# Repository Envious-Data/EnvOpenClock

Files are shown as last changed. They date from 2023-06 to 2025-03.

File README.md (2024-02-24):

# Env-OpenClock
 A fancy lil clock using 8x LTP-305s and a Raspberry Pi Pico.

## Information
This clock features a DS3231 but it doesnt have its own onboard battery management meaning its meant to have constant power but there is nothing stopping anyone from soldering something like a pico lipo shim to the back of the PCB. The RTC is mainly for convenience.

There are 4 buttons and a switch, The switch is meant for Summer time adjustment and the 4 buttons are for setting the time or alarm.

## Implemented Features
- Time Setting
- Date Mode

## Planned software features
(Some ideas, may not get implemented)
- Animated text to show time has been set?
- Animated Transition to menus?
- A menu system
- Alarm system
- Text Marquee modes

## Planned Hardware features
In the current version of the board there is a a DS3231 w/ CR1220 battery, Raspberry pi pico, 4x tactile buttons, 4x IS31FL37s, a small piezo speaker and amp and obviously the 8x LTP305 sockets.

We'd like to change this to have easier to press buttons, a larger battery holder, the speaker may not get re-implemented, we'll see when we decide to move toward finalizing the design and preparing for order. Keep in mind that TIL305s have been discontinued for a long time and LTP305s are now discontinued and hard to get so we'll substitute our own "DIY305" which is a dip14 sized PCB with standard headers and 0402 leds but we have made a 0201 version but may not use it due to cost.

## Hardware
I designed the board in KiCad, you can use various plugins to generate production files for your chosen PCB FAB
Some aspects may change but I generally intend to keep the formfactor the same and all the components on one side for cheaper manufacturing.

since the board uses 8x LTP305s you can also display the date instead of the time, the RTC does store the date as well as the time, currently as of writing this the firmware only displays the current time stored on the DS3231 RTC, but the main planned features are day/date/time setting and then goals can expand. Its possible to add text marquee too.

## PCBWAY
PCBWAY (http://pcbway.com)

[PCBWAY](http://pcbway.com) Kindly sponsored a batch of PCBs of which you can see a video of the board working below

https://github.com/Envious-Data/Env-OpenClock/assets/5001879/fdac6cdb-803a-443c-b91d-f5f40f54c28f

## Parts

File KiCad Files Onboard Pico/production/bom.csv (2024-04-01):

Designator | Footprint | Quantity | Value | LCSC Part #
BT1 | BatteryHolder_Keystone_3034_1x20mm | 1 | Keystone 3034
BZ1 | Buzzer_TDK_PS1240P02BT_D12.2mm_H6.5mm | 1 | Buzzer 12.2Mm
C1, C3, C33, C5, C7, C9 | 0402 | 6 | 0402 0.1uF
C10, C2, C4, C6, C8 | 0402 | 5 | 0402 1uF
C11, C12, C13, C14 | 0402 | 4 | 0402 10uF
C16, C17 | 0402 | 2 | 22pf 0402
C18, C21, C22, C24, C26, C27, C28, C29, C30, C31 | 0402 | 10 | 100nf 0402
C19, C20, CBP1 | 0402 | 3 | 10uf 0402
C23 | 0402 | 1 | 1uf 0402
C25 | 0402 | 1 | 2.2uF 0402
D1 | D_SOD-123 | 1 | 1N4002W
F1 | 0805 | 1 | 0805L050WR
FB1 | 0402 | 1 | FerriteBead 0402
FLASH1 | SON-8-1EP_3x2mm_P0.5mm_EP1.4x1.6mm | 1 | W25Q16JVUXIQ
H1, H2, H3, H4 | MountingHole_2.2mm_M2 | 4 | M2
IC1, IC2, IC3, IC4 | QFN-24-1EP_4x4mm_P0.5mm_EP2.6x2.6mm_ThermalVias | 4 | IS31FL3730-QFLS2-TR
J1 | PinHeader_1x03_P1.00mm_Vertical | 1 | 1mm 1x3
J3 | SW_Push_SPST_NO_Alps_SKRK | 1 | Button
JP1 | SolderJumper-2_P1.3mm_Bridged_RoundedPad1.0x1.5mm | 1 | bridge
JP2, JP3 | SolderJumper-2_P1.3mm_Open_RoundedPad1.0x1.5mm | 2 | bridge
M1, M2, M3, M4, M5, M6, M7, M8 | DIP-14_W7.62mm_Socket | 8 | Dip-14 Socket
Q1 | SOT-23 | 1 | 2SC1815
R1, R10, R11, R12, R13, R2, R28, R5, R6, R7, R8, R9 | 0402 | 12 | 0402 10K
R15, R16 | 0402 | 2 | 5.1K 0402
R18, R23 | 0402 | 2 | 1K 0402
R21 | 0402 | 1 | 10K 0402
R22 | 0402 | 1 | 100K 0402
R24, R25 | 0402 | 2 | 27r 0402 resistor
R3, R4 | 0805 | 2 | 0805 1K
RSW1 | SW_Push_SPST_NO_Alps_SKRK | 1 | TSA343G00-250J2
SW1, SW2, SW3, SW4, SW5 | SW_Cherry_MX_1.00u_PCB | 5 | MX Keyboard Switch
TP1, TP2, TP3 | TestPoint_Pad_D1.0mm | 3 | TestPoint
U1 | DFN-6-1EP_3x3mm_P1mm_EP1.5x2.4mm | 1 | Si7021-A20
U2 | SOT-23-5 | 1 | TLV75733PDBVR
U3 | SOIC-16W_7.5x10.3mm_P1.27mm | 1 | DS3231M
U4 | RP2040-QFN-56 | 1 | RP2040 | C2040
USB1 | USB_C_Receptacle_HRO_TYPE-C-31-M-12 | 1 | TYPE-C-31-M-12 | C165948
Y1 | Crystal_SMD_3225-4Pin_3.2x2.5mm | 1 | 3225_4P 12MHz

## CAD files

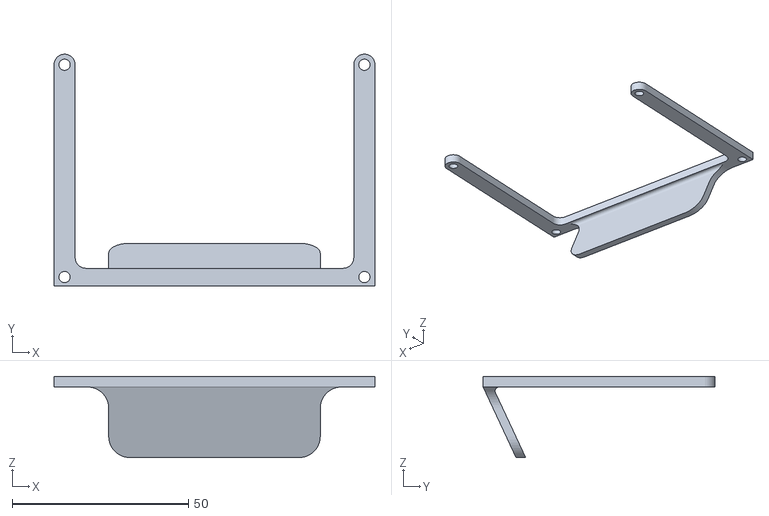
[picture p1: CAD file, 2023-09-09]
3d files/Simple Stand.stl
91.0 x 65.7 x 23.0

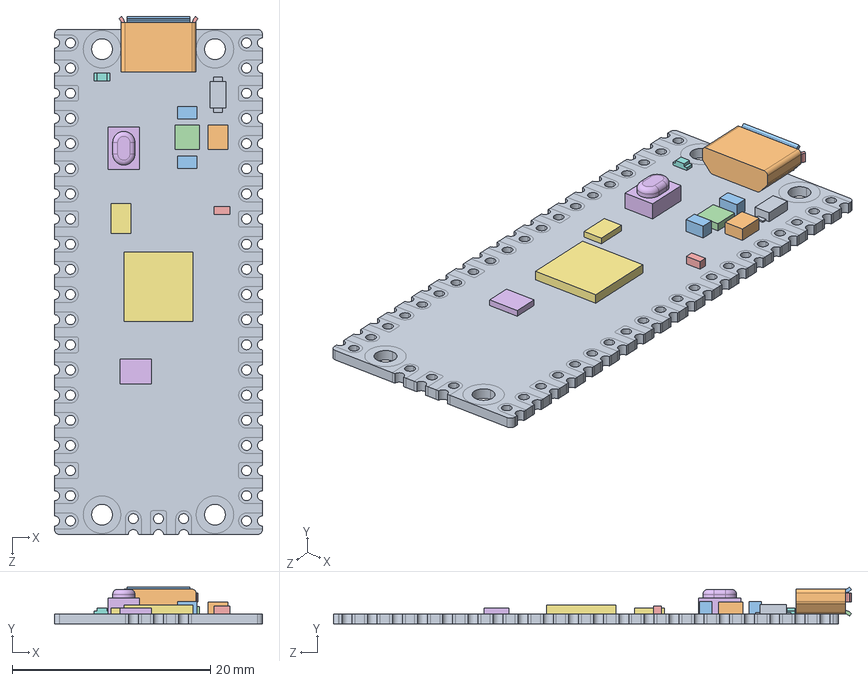
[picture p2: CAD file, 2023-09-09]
KiCad Files Onboard Pico/Resources/Pico-R3.step
21.0 x 3.73 x 52.3 mm
PICO_REF_BOARD.STEP
PICO_REF_USB.STEP
PICO_REF_SWITCH.STEP
PICO_REF_MICROCONTROLLER.STEP
PICO_REF_LED.STEP
PICO_REF_ONSEMI.STEP
PICO_BOURNS.STEP
PICO_MURATA.STEP x 2
PICO_RICHTEK.STEP
PICO_DIODES.STEP
PICO_AEL.STEP
PICO_WINBOND.STEP

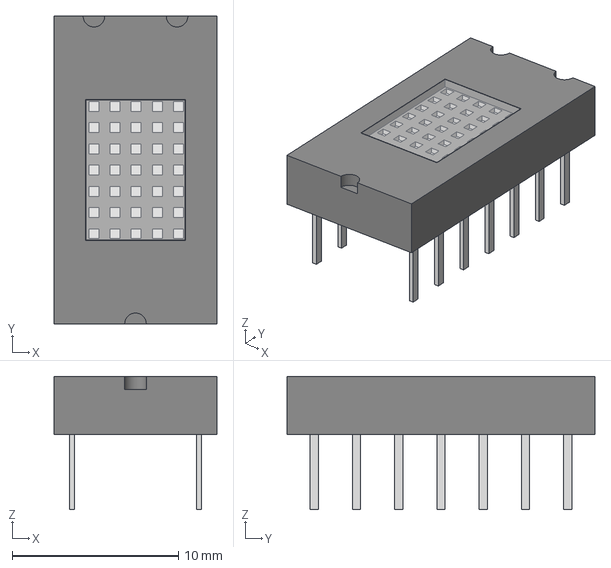
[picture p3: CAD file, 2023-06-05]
KiCad Files Onboard Pico/Resources/LTP-305G.stp
9.80 x 18.5 x 8.00 mm

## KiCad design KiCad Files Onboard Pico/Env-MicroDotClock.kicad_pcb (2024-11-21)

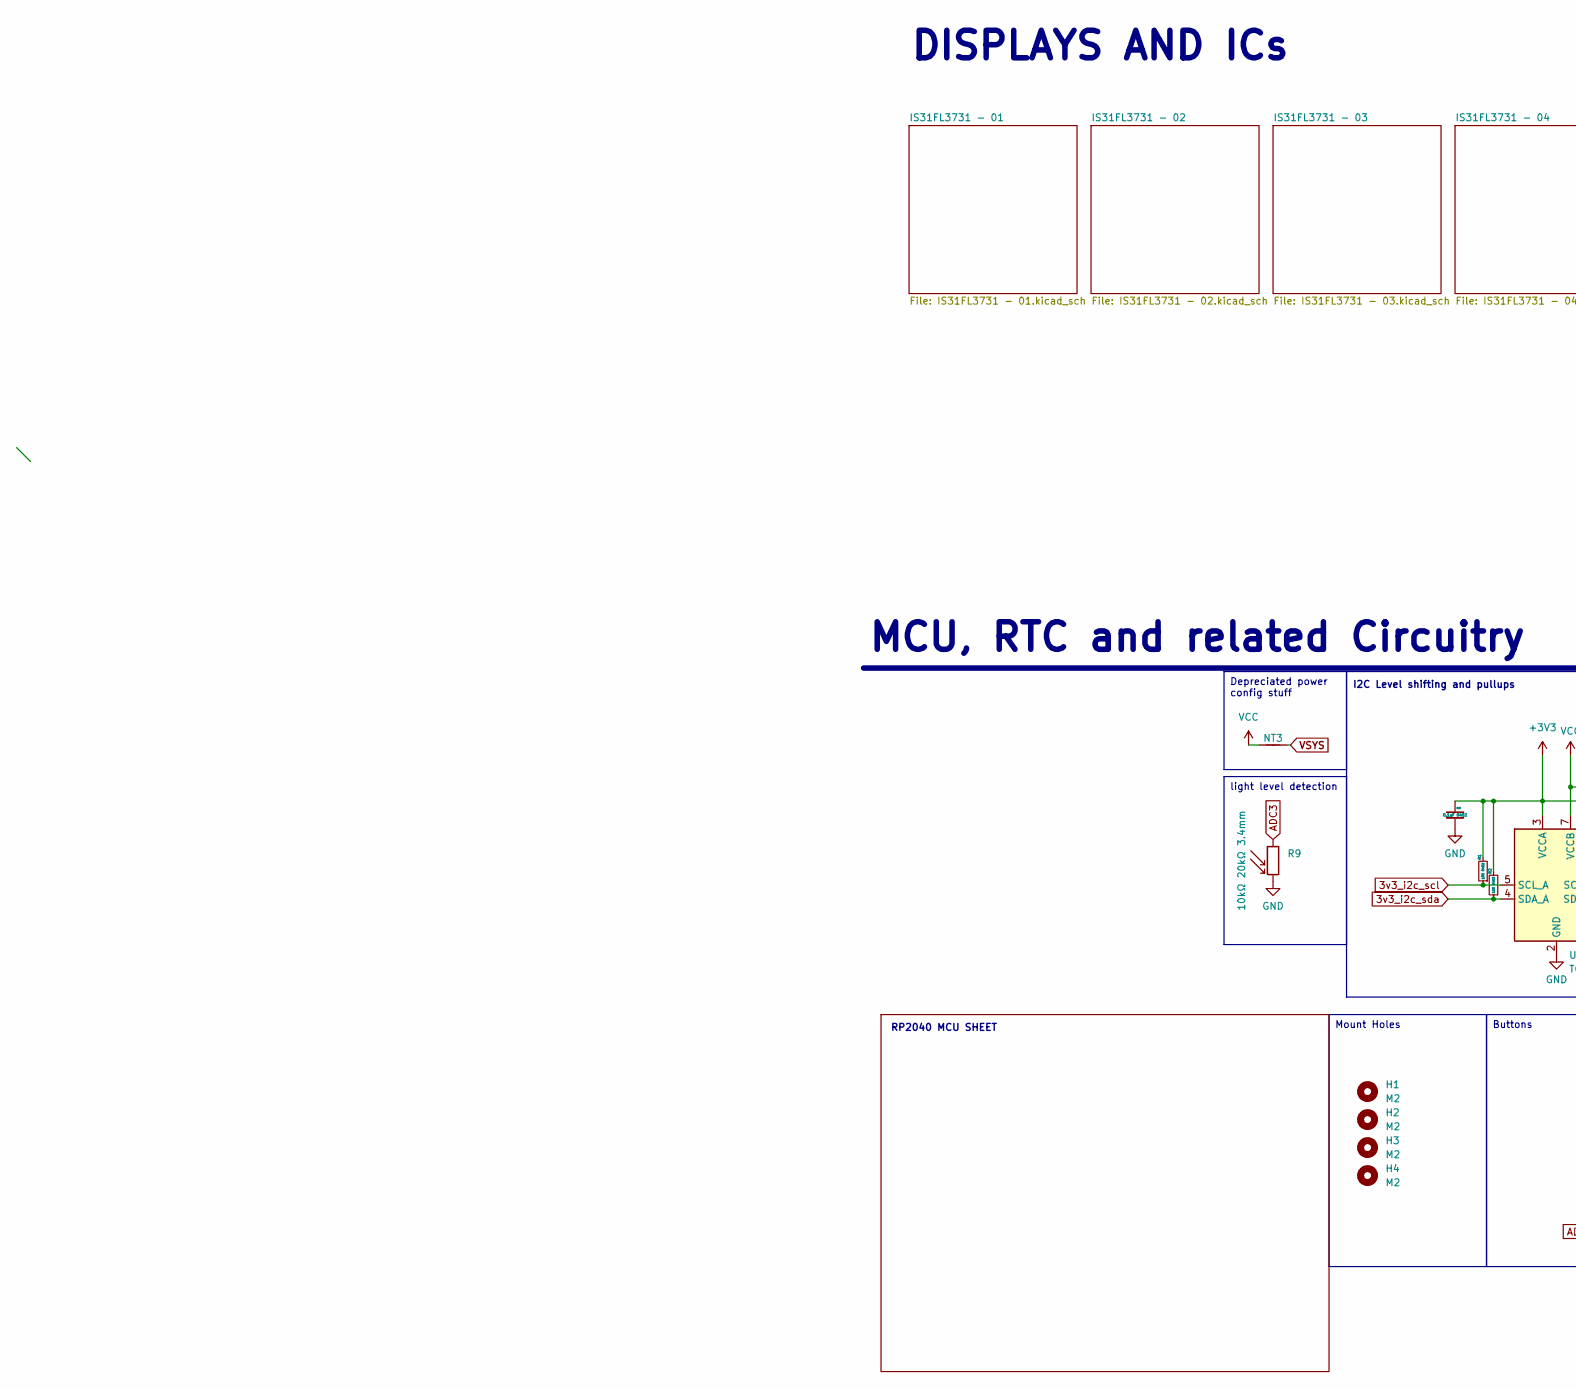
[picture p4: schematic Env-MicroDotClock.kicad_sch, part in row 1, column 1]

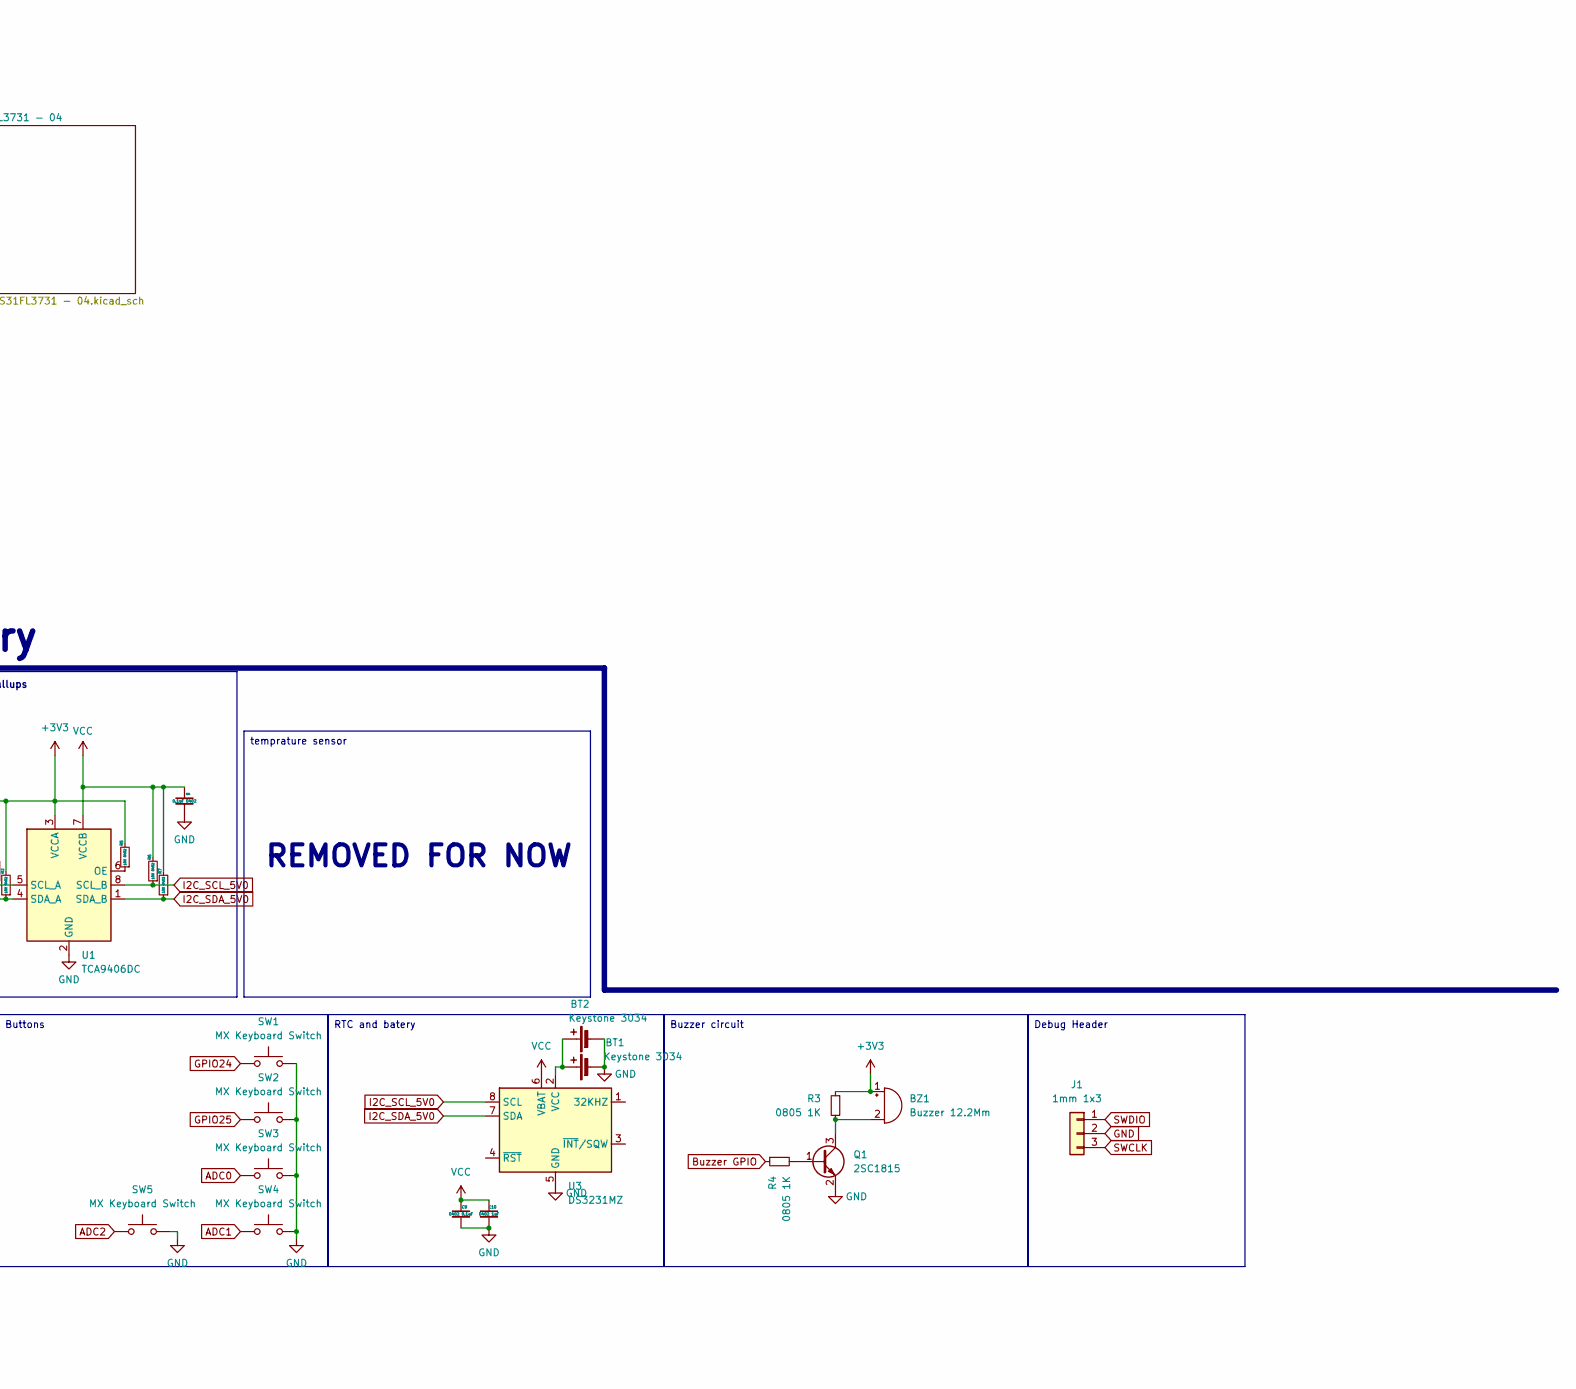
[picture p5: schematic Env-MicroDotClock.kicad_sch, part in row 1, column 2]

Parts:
BT1, BT2: Keystone 3034; BatteryHolder_Keystone_3034_1x20mm
BZ1: Buzzer 12.2Mm; Buzzer_TDK_PS1240P02BT_D12.2mm_H6.5mm
C9: 0402 0.1uF; C_0402_1005Metric
C10: 0402 1uF; C_0402_1005Metric
C33, C34: 0.1uF 0402; C_0402_1005Metric
H1, H2, H3, H4: M2; MountingHole_2.2mm_M2
J1: 1mm 1x3; PinHeader_1x03_P1.00mm_Vertical
NT3: NetTie_2; NetTie-2_THT_Pad0.3mm
Q1: 2SC1815; SOT-23
R1, R2, R5, R6, R7: 10K 0402; R_0402_1005Metric
R3, R4: 0805 1K; R_0805_2012Metric
R9: 10kΩ 20kΩ 3.4mm; R_LDR_5.1x4.3mm_P3.4mm_Vertical
SW1, SW2, SW3, SW4, SW5: MX Keyboard Switch; SW_Cherry_MX_1.00u_PCB
U1: TCA9406DC; VSSOP-8_2.3x2mm_P0.5mm
U3: DS3231MZ; SOIC-8_3.9x4.9mm_P1.27mm

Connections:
3v3_i2c_scl: R1.1, U1.5 (SCL_A); also elsewhere on the board
3v3_i2c_sda: R2.1, U1.4 (SDA_A); also elsewhere on the board
+3V3: BZ1.1 (-), C33.1, R1.2, R2.2, R3.1, R5.2, U1.3 (VCCA); also elsewhere on the board
ADC0: SW3.1; also elsewhere on the board
ADC1: SW4.1; also elsewhere on the board
ADC2: SW5.1; also elsewhere on the board
ADC3: R9.1; also elsewhere on the board
Buzzer GPIO: R4.1; also elsewhere on the board
GND: BT1.2 (-), BT2.2 (-), C9.2, C10.2, C33.2, C34.2, J1.2, Q1.2 (E), R9.2, SW1.2, SW2.2, SW3.2, SW4.2, SW5.2, U1.2 (GND), U3.5 (GND); also elsewhere on the board
GPIO24: SW1.1; also elsewhere on the board
GPIO25: SW2.1; also elsewhere on the board
I2C_SCL_5V0: R6.1, U1.8 (SCL_B), U3.8 (SCL); also elsewhere on the board
I2C_SDA_5V0: R7.1, U1.1 (SDA_B), U3.7 (SDA); also elsewhere on the board
unnamed: BT1.1 (+), BT2.1 (+), U3.2 (VCC)
unnamed: BZ1.2 (+), Q1.3 (C), R3.2
unnamed: Q1.1 (B), R4.2
unnamed: R5.1, U1.6 (OE)
SWCLK: J1.3; also elsewhere on the board
SWDIO: J1.1; also elsewhere on the board
VCC: C9.1, C10.1, C34.1, NT3.1, R6.2, R7.2, U1.7 (VCCB), U3.6 (VBAT); also elsewhere on the board
VSYS: NT3.2; also elsewhere on the board

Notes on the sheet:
light level detection
RTC and batery
Mount Holes
Depreciated power config stuff
Buzzer circuit
Debug Header
Buttons
temprature sensor
DISPLAYS AND ICs
MCU, RTC and related Circuitry
RP2040 MCU SHEET
I2C Level shifting and pullups
REMOVED FOR NOW

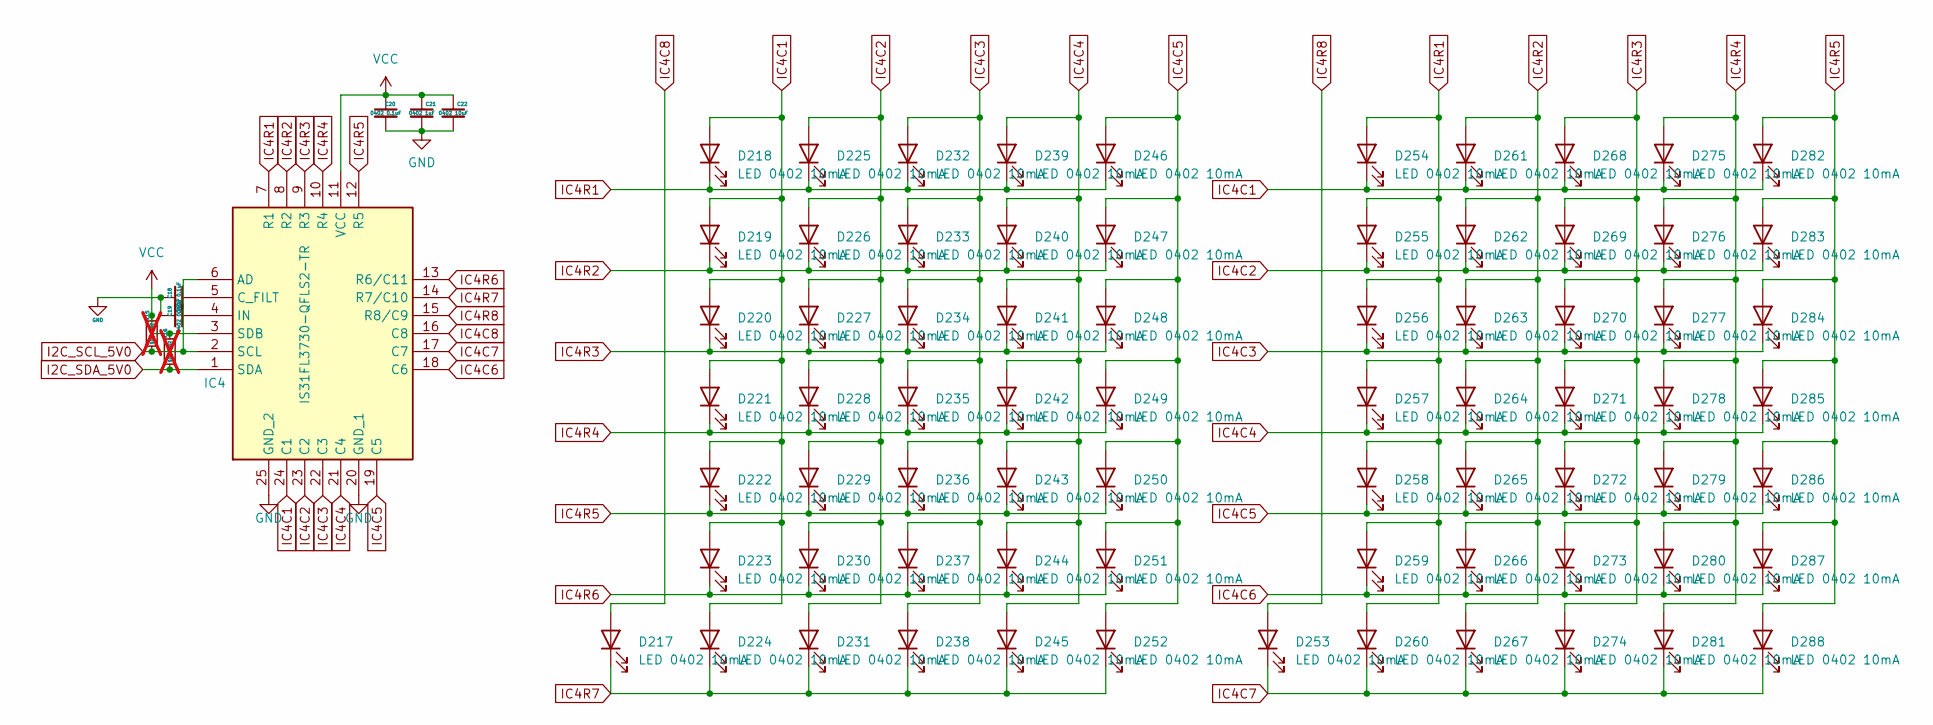
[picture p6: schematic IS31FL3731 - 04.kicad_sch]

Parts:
C18, C20: 0402 0.1uF; C_0402_1005Metric
C19: 0402 0.22uF; C_0402_1005Metric
C21: 0402 1uF; C_0402_1005Metric
C22: 0402 10uF; C_0402_1005Metric
D217, D218, D219, D220, D221, D222, D223, D224, D225, D226, D227, D228, D229, D230, D231, D232, D233, D234, D235, D236, D237, D238, D239, D240, D241, D242, D243, D244, D245, D246, D247, D248, D249, D250, D251, D252, D253, D254, D255, D256, D257, D258, D259, D260, D261, D262, D263, D264, D265, D266, D267, D268, D269, D270, D271, D272, D273, D274, D275, D276, D277, D278, D279, D280, D281, D282, D283, D284, D285, D286, D287, D288: LED 0402 10mA; LED_0402_1005Metric
IC4: IS31FL3730-QFLS2-TR; QFN-24-1EP_4x4mm_P0.5mm_EP2.6x2.6mm_ThermalVias; Mouser Part Number 870-IS31FL3730QFLS2R
R15, R16: 10K 0402; R_0402_1005Metric; not fitted

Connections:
GND: C18.1, C19.1, C20.2, C21.2, C22.2, IC4.20 (GND_1), IC4.25 (GND_2); also elsewhere on the board
I2C_SCL_5V0: IC4.2 (SCL), IC4.6 (AD), R15.1; also elsewhere on the board
I2C_SDA_5V0: IC4.1 (SDA), R16.1; also elsewhere on the board
IC4C1: D218.2 (A), D219.2 (A), D220.2 (A), D221.2 (A), D222.2 (A), D223.2 (A), D224.2 (A), D254.1 (K), D261.1 (K), D268.1 (K), D275.1 (K), D282.1 (K), IC4.24 (C1)
IC4C2: D225.2 (A), D226.2 (A), D227.2 (A), D228.2 (A), D229.2 (A), D230.2 (A), D231.2 (A), D255.1 (K), D262.1 (K), D269.1 (K), D276.1 (K), D283.1 (K), IC4.23 (C2)
IC4C3: D232.2 (A), D233.2 (A), D234.2 (A), D235.2 (A), D236.2 (A), D237.2 (A), D238.2 (A), D256.1 (K), D263.1 (K), D270.1 (K), D277.1 (K), D284.1 (K), IC4.22 (C3)
IC4C4: D239.2 (A), D240.2 (A), D241.2 (A), D242.2 (A), D243.2 (A), D244.2 (A), D245.2 (A), D257.1 (K), D264.1 (K), D271.1 (K), D278.1 (K), D285.1 (K), IC4.21 (C4)
IC4C5: D246.2 (A), D247.2 (A), D248.2 (A), D249.2 (A), D250.2 (A), D251.2 (A), D252.2 (A), D258.1 (K), D265.1 (K), D272.1 (K), D279.1 (K), D286.1 (K), IC4.19 (C5)
IC4C6: D259.1 (K), D266.1 (K), D273.1 (K), D280.1 (K), D287.1 (K), IC4.18 (C6)
IC4C7: D253.1 (K), D260.1 (K), D267.1 (K), D274.1 (K), D281.1 (K), D288.1 (K), IC4.17 (C7)
IC4C8: D217.2 (A), IC4.16 (C8)
IC4R1: D218.1 (K), D225.1 (K), D232.1 (K), D239.1 (K), D246.1 (K), D254.2 (A), D255.2 (A), D256.2 (A), D257.2 (A), D258.2 (A), D259.2 (A), D260.2 (A), IC4.7 (R1)
IC4R2: D219.1 (K), D226.1 (K), D233.1 (K), D240.1 (K), D247.1 (K), D261.2 (A), D262.2 (A), D263.2 (A), D264.2 (A), D265.2 (A), D266.2 (A), D267.2 (A), IC4.8 (R2)
IC4R3: D220.1 (K), D227.1 (K), D234.1 (K), D241.1 (K), D248.1 (K), D268.2 (A), D269.2 (A), D270.2 (A), D271.2 (A), D272.2 (A), D273.2 (A), D274.2 (A), IC4.9 (R3)
IC4R4: D221.1 (K), D228.1 (K), D235.1 (K), D242.1 (K), D249.1 (K), D275.2 (A), D276.2 (A), D277.2 (A), D278.2 (A), D279.2 (A), D280.2 (A), D281.2 (A), IC4.10 (R4)
IC4R5: D222.1 (K), D229.1 (K), D236.1 (K), D243.1 (K), D250.1 (K), D282.2 (A), D283.2 (A), D284.2 (A), D285.2 (A), D286.2 (A), D287.2 (A), D288.2 (A), IC4.12 (R5)
IC4R6: D223.1 (K), D230.1 (K), D237.1 (K), D244.1 (K), D251.1 (K), IC4.13 (R6/C11)
IC4R7: D217.1 (K), D224.1 (K), D231.1 (K), D238.1 (K), D245.1 (K), D252.1 (K), IC4.14 (R7/C10)
IC4R8: D253.2 (A), IC4.15 (R8/C9)
unnamed: C18.2, IC4.5 (C_FILT)
unnamed: C19.2, IC4.4 (IN)
VCC: C20.1, C21.1, C22.1, IC4.3 (SDB), IC4.11 (VCC), R15.2, R16.2; also elsewhere on the board

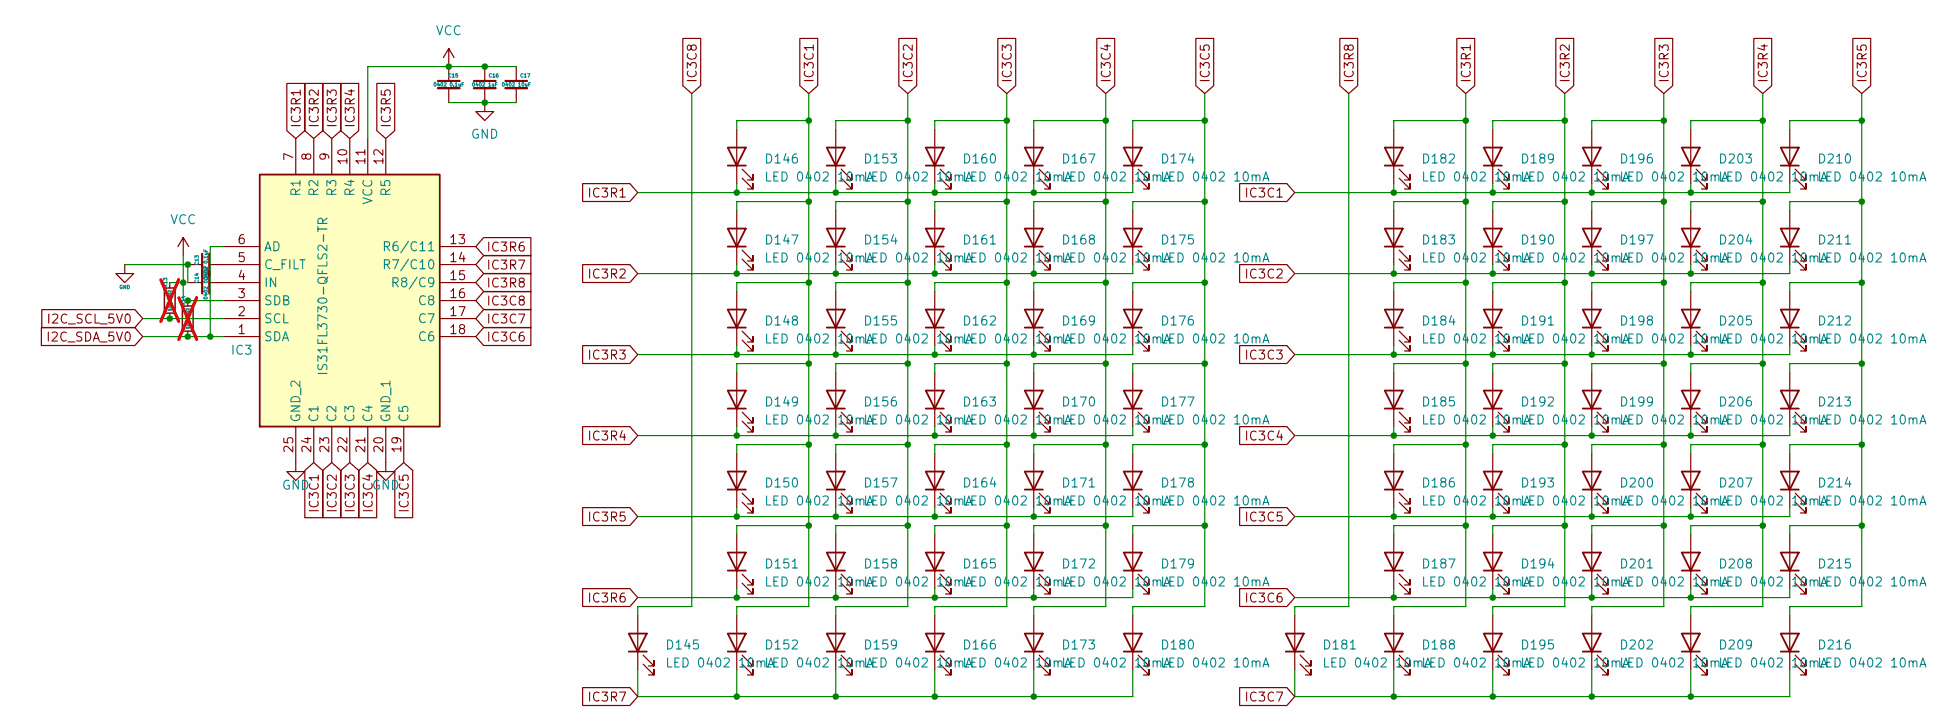
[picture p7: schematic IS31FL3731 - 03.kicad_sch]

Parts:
C13, C15: 0402 0.1uF; C_0402_1005Metric
C14: 0402 0.22uF; C_0402_1005Metric
C16: 0402 1uF; C_0402_1005Metric
C17: 0402 10uF; C_0402_1005Metric
D145, D146, D147, D148, D149, D150, D151, D152, D153, D154, D155, D156, D157, D158, D159, D160, D161, D162, D163, D164, D165, D166, D167, D168, D169, D170, D171, D172, D173, D174, D175, D176, D177, D178, D179, D180, D181, D182, D183, D184, D185, D186, D187, D188, D189, D190, D191, D192, D193, D194, D195, D196, D197, D198, D199, D200, D201, D202, D203, D204, D205, D206, D207, D208, D209, D210, D211, D212, D213, D214, D215, D216: LED 0402 10mA; LED_0402_1005Metric
IC3: IS31FL3730-QFLS2-TR; QFN-24-1EP_4x4mm_P0.5mm_EP2.6x2.6mm_ThermalVias; Mouser Part Number 870-IS31FL3730QFLS2R
R13, R14: 10K 0402; R_0402_1005Metric; not fitted

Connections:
GND: C13.1, C14.1, C15.2, C16.2, C17.2, IC3.20 (GND_1), IC3.25 (GND_2); also elsewhere on the board
I2C_SCL_5V0: IC3.2 (SCL), R13.1; also elsewhere on the board
I2C_SDA_5V0: IC3.1 (SDA), IC3.6 (AD), R14.1; also elsewhere on the board
IC3C1: D146.2 (A), D147.2 (A), D148.2 (A), D149.2 (A), D150.2 (A), D151.2 (A), D152.2 (A), D182.1 (K), D189.1 (K), D196.1 (K), D203.1 (K), D210.1 (K), IC3.24 (C1)
IC3C2: D153.2 (A), D154.2 (A), D155.2 (A), D156.2 (A), D157.2 (A), D158.2 (A), D159.2 (A), D183.1 (K), D190.1 (K), D197.1 (K), D204.1 (K), D211.1 (K), IC3.23 (C2)
IC3C3: D160.2 (A), D161.2 (A), D162.2 (A), D163.2 (A), D164.2 (A), D165.2 (A), D166.2 (A), D184.1 (K), D191.1 (K), D198.1 (K), D205.1 (K), D212.1 (K), IC3.22 (C3)
IC3C4: D167.2 (A), D168.2 (A), D169.2 (A), D170.2 (A), D171.2 (A), D172.2 (A), D173.2 (A), D185.1 (K), D192.1 (K), D199.1 (K), D206.1 (K), D213.1 (K), IC3.21 (C4)
IC3C5: D174.2 (A), D175.2 (A), D176.2 (A), D177.2 (A), D178.2 (A), D179.2 (A), D180.2 (A), D186.1 (K), D193.1 (K), D200.1 (K), D207.1 (K), D214.1 (K), IC3.19 (C5)
IC3C6: D187.1 (K), D194.1 (K), D201.1 (K), D208.1 (K), D215.1 (K), IC3.18 (C6)
IC3C7: D181.1 (K), D188.1 (K), D195.1 (K), D202.1 (K), D209.1 (K), D216.1 (K), IC3.17 (C7)
IC3C8: D145.2 (A), IC3.16 (C8)
IC3R1: D146.1 (K), D153.1 (K), D160.1 (K), D167.1 (K), D174.1 (K), D182.2 (A), D183.2 (A), D184.2 (A), D185.2 (A), D186.2 (A), D187.2 (A), D188.2 (A), IC3.7 (R1)
IC3R2: D147.1 (K), D154.1 (K), D161.1 (K), D168.1 (K), D175.1 (K), D189.2 (A), D190.2 (A), D191.2 (A), D192.2 (A), D193.2 (A), D194.2 (A), D195.2 (A), IC3.8 (R2)
IC3R3: D148.1 (K), D155.1 (K), D162.1 (K), D169.1 (K), D176.1 (K), D196.2 (A), D197.2 (A), D198.2 (A), D199.2 (A), D200.2 (A), D201.2 (A), D202.2 (A), IC3.9 (R3)
IC3R4: D149.1 (K), D156.1 (K), D163.1 (K), D170.1 (K), D177.1 (K), D203.2 (A), D204.2 (A), D205.2 (A), D206.2 (A), D207.2 (A), D208.2 (A), D209.2 (A), IC3.10 (R4)
IC3R5: D150.1 (K), D157.1 (K), D164.1 (K), D171.1 (K), D178.1 (K), D210.2 (A), D211.2 (A), D212.2 (A), D213.2 (A), D214.2 (A), D215.2 (A), D216.2 (A), IC3.12 (R5)
IC3R6: D151.1 (K), D158.1 (K), D165.1 (K), D172.1 (K), D179.1 (K), IC3.13 (R6/C11)
IC3R7: D145.1 (K), D152.1 (K), D159.1 (K), D166.1 (K), D173.1 (K), D180.1 (K), IC3.14 (R7/C10)
IC3R8: D181.2 (A), IC3.15 (R8/C9)
unnamed: C13.2, IC3.5 (C_FILT)
unnamed: C14.2, IC3.4 (IN)
VCC: C15.1, C16.1, C17.1, IC3.3 (SDB), IC3.11 (VCC), R13.2, R14.2; also elsewhere on the board

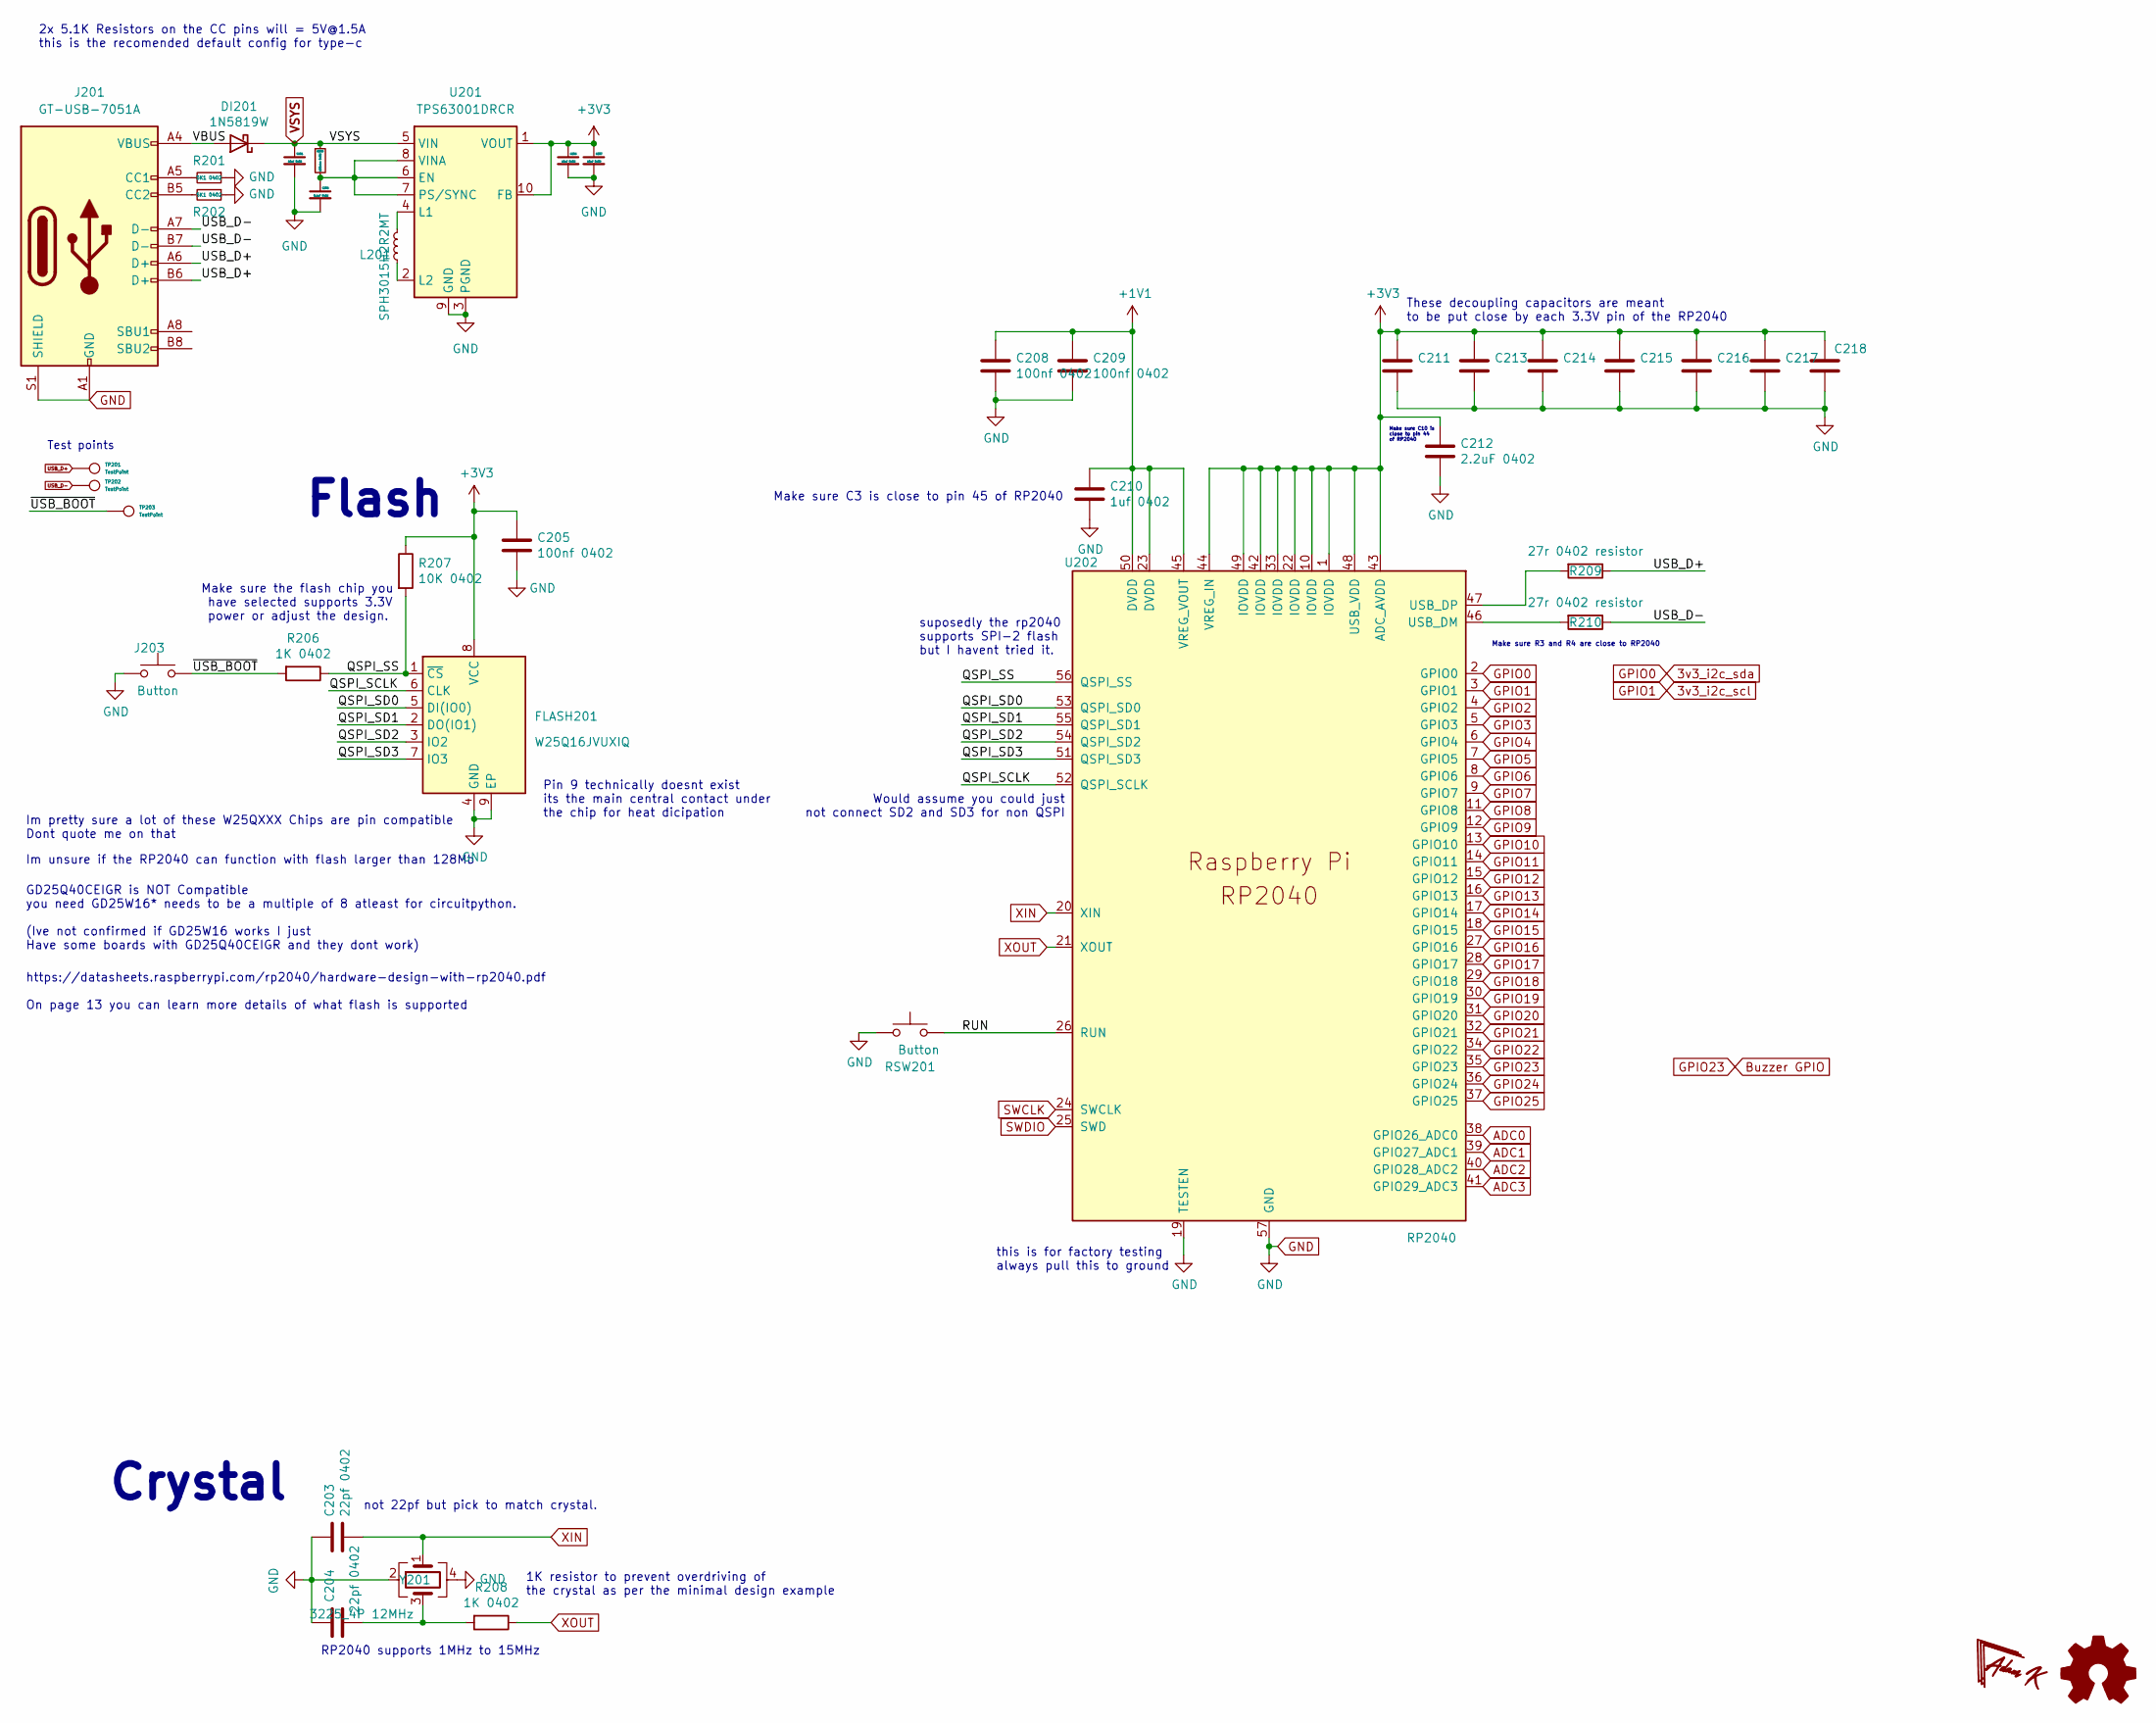
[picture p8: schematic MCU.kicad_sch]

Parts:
C201, C206, C207: 10uF 0402; C_0402_1005Metric
C202: 0.1uF 0402; C_0402_1005Metric
C203, C204: 22pf 0402; C_0402_1005Metric
C205, C208, C209, C211, C213, C214, C215, C216, C217, C218: 100nf 0402; C_0402_1005Metric
C210: 1uf 0402; C_0402_1005Metric
C212: 2.2uF 0402; C_0402_1005Metric
DI201: 1N5819W; D_SOD-123
FLASH201: W25Q16JVUXIQ; SON-8-1EP_3x2mm_P0.5mm_EP1.4x1.6mm
J201: GT-USB-7051A; USB_C_Receptacle_G-Switch_GT-USB-7051x
J203: Button; SW_SPST_B3U-1000P-B
L201: SPH3015H2R2MT; L_Sunlord_SWPA3015S
R201, R202: 5K1 0402; R_0402_1005Metric
R205: 100ohm 0402; R_0402_1005Metric
R206, R208: 1K 0402; R_0402_1005Metric
R207: 10K 0402; R_0402_1005Metric
R209, R210: 27r 0402 resistor; R_0402_1005Metric
RSW201: Button; SW_SPST_B3U-1000P-B
TP201, TP202, TP203: TestPoint; TestPoint_Pad_D1.0mm
U201: TPS63001DRCR; Texas_DRC0010J_ThermalVias
U202: RP2040; RP2040-QFN-56; LCSC C2040
Y201: 3225_4P 12MHz; Crystal_SMD_3225-4Pin_3.2x2.5mm

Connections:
3v3_i2c_scl: U202.3 (GPIO1); also elsewhere on the board
3v3_i2c_sda: U202.2 (GPIO0); also elsewhere on the board
+1V1: C208.1, C209.1, C210.1, U202.23 (DVDD), U202.45 (VREG_VOUT), U202.50 (DVDD)
+3V3: C205.1, C206.1, C207.1, C211.1, C212.1, C213.1, C214.1, C215.1, C216.1, C217.1, C218.1, FLASH201.8 (VCC), R207.1, U201.1 (VOUT), U201.10 (FB), U202.1 (IOVDD), U202.10 (IOVDD), U202.22 (IOVDD), U202.33 (IOVDD), U202.42 (IOVDD), U202.43 (ADC_AVDD), U202.44 (VREG_IN), U202.48 (USB_VDD), U202.49 (IOVDD); also elsewhere on the board
/Onboard Pico/QSPI_SCLK: FLASH201.6 (CLK), U202.52 (QSPI_SCLK)
/Onboard Pico/QSPI_SD0: FLASH201.5 (DI(IO0)), U202.53 (QSPI_SD0)
/Onboard Pico/QSPI_SD1: FLASH201.2 (DO(IO1)), U202.55 (QSPI_SD1)
/Onboard Pico/QSPI_SD2: FLASH201.3 (IO2), U202.54 (QSPI_SD2)
/Onboard Pico/QSPI_SD3: FLASH201.7 (IO3), U202.51 (QSPI_SD3)
/Onboard Pico/QSPI_SS: FLASH201.1 (~CS), R206.1, R207.2, U202.56 (QSPI_SS)
/Onboard Pico/RUN: RSW201.2, U202.26 (RUN)
/Onboard Pico/VBUS: DI201.2 (A), J201.A4 (VBUS), J201.A9 (VBUS), J201.B4 (VBUS), J201.B9 (VBUS)
/Onboard Pico/~USB_BOOT: J203.1, R206.2
ADC0: U202.38 (GPIO26_ADC0); also elsewhere on the board
ADC1: U202.39 (GPIO27_ADC1); also elsewhere on the board
ADC2: U202.40 (GPIO28_ADC2); also elsewhere on the board
ADC3: U202.41 (GPIO29_ADC3); also elsewhere on the board
Buzzer GPIO: U202.35 (GPIO23); also elsewhere on the board
GND: C201.2, C202.2, C203.1, C204.1, C205.2, C206.2, C207.2, C208.2, C209.2, C210.2, C211.2, C212.2, C213.2, C214.2, C215.2, C216.2, C217.2, C218.2, FLASH201.4 (GND), FLASH201.9 (EP), J201.A1 (GND), J201.A12 (GND), J201.B1 (GND), J201.B12 (GND), J201.S1 (SHIELD), J203.2, R201.1, R202.1, RSW201.1, U201.3 (PGND), U201.9 (GND), U201.11 (PGND), U202.19 (TESTEN), U202.57 (GND), Y201.2, Y201.4; also elsewhere on the board
GPIO2: U202.4 (GPIO2)
GPIO3: U202.5 (GPIO3)
GPIO4: U202.6 (GPIO4)
GPIO5: U202.7 (GPIO5)
GPIO6: U202.8 (GPIO6)
GPIO7: U202.9 (GPIO7)
GPIO8: U202.11 (GPIO8)
GPIO9: U202.12 (GPIO9)
GPIO10: U202.13 (GPIO10)
GPIO11: U202.14 (GPIO11)
GPIO12: U202.15 (GPIO12)
GPIO13: U202.16 (GPIO13)
GPIO14: U202.17 (GPIO14)
GPIO15: U202.18 (GPIO15)
GPIO16: U202.27 (GPIO16)
GPIO17: U202.28 (GPIO17)
GPIO18: U202.29 (GPIO18)
GPIO19: U202.30 (GPIO19)
GPIO20: U202.31 (GPIO20)
GPIO21: U202.32 (GPIO21)
GPIO22: U202.34 (GPIO22)
GPIO24: U202.36 (GPIO24); also elsewhere on the board
GPIO25: U202.37 (GPIO25); also elsewhere on the board
unnamed: C204.2, R208.2, Y201.3
unnamed: J201.A5 (CC1), R201.2
unnamed: J201.B5 (CC2), R202.2
unnamed: C202.1, R205.2, U201.6 (EN), U201.7 (PS/SYNC), U201.8 (VINA)
unnamed: L201.1, U201.4 (L1)
unnamed: L201.2, U201.2 (L2)
unnamed: R210.2, U202.46 (USB_DM)
unnamed: R209.2, U202.47 (USB_DP)
SWCLK: U202.24 (SWCLK); also elsewhere on the board
SWDIO: U202.25 (SWD); also elsewhere on the board
USB_D+: J201.A6 (D+), J201.B6 (D+), R209.1, TP201.1
USB_D-: J201.A7 (D-), J201.B7 (D-), R210.1, TP202.1
VSYS: C201.1, DI201.1 (K), R205.1, U201.5 (VIN); also elsewhere on the board
XIN: C203.2, U202.20 (XIN), Y201.1
XOUT: R208.1, U202.21 (XOUT)

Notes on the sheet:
GD25Q40CEIGR is NOT Compatible you need GD25W16* needs to be a multiple of 8 atleast for circuitpython. (Ive not confirmed if GD25W16 works I just Have some boards with GD25Q40CEIGR and they dont work)
1K resistor to prevent overdriving of the crystal as per the minimal design example
RP2040 supports 1MHz to 15MHz
https://datasheets.raspberrypi.com/rp2040/hardware-design-with-rp2040.pdf On page 13 you can learn more details of what flash is supported
Flash
Im pretty sure a lot of these W25QXXX Chips are pin compatible Dont quote me on that
suposedly the rp2040 supports SPI-2 flash but I havent tried it.
Would assume you could just not connect SD2 and SD3 for non QSPI
Make sure the flash chip you have selected supports 3.3V power or adjust the design.
Test points
2x 5.1K Resistors on the CC pins will = 5V@1.5A this is the recomended default config for type-c
Im unsure if the RP2040 can function with flash larger than 128Mb
not 22pf but pick to match crystal.
Pin 9 technically doesnt exist its the main central contact under the chip for heat dicipation
These decoupling capacitors are meant to be put close by each 3.3V pin of the RP2040
Crystal
Make sure R3 and R4 are close to RP2040
Make sure C10 is close to pin 44 of RP2040
Make sure C3 is close to pin 45 of RP2040
this is for factory testing always pull this to ground

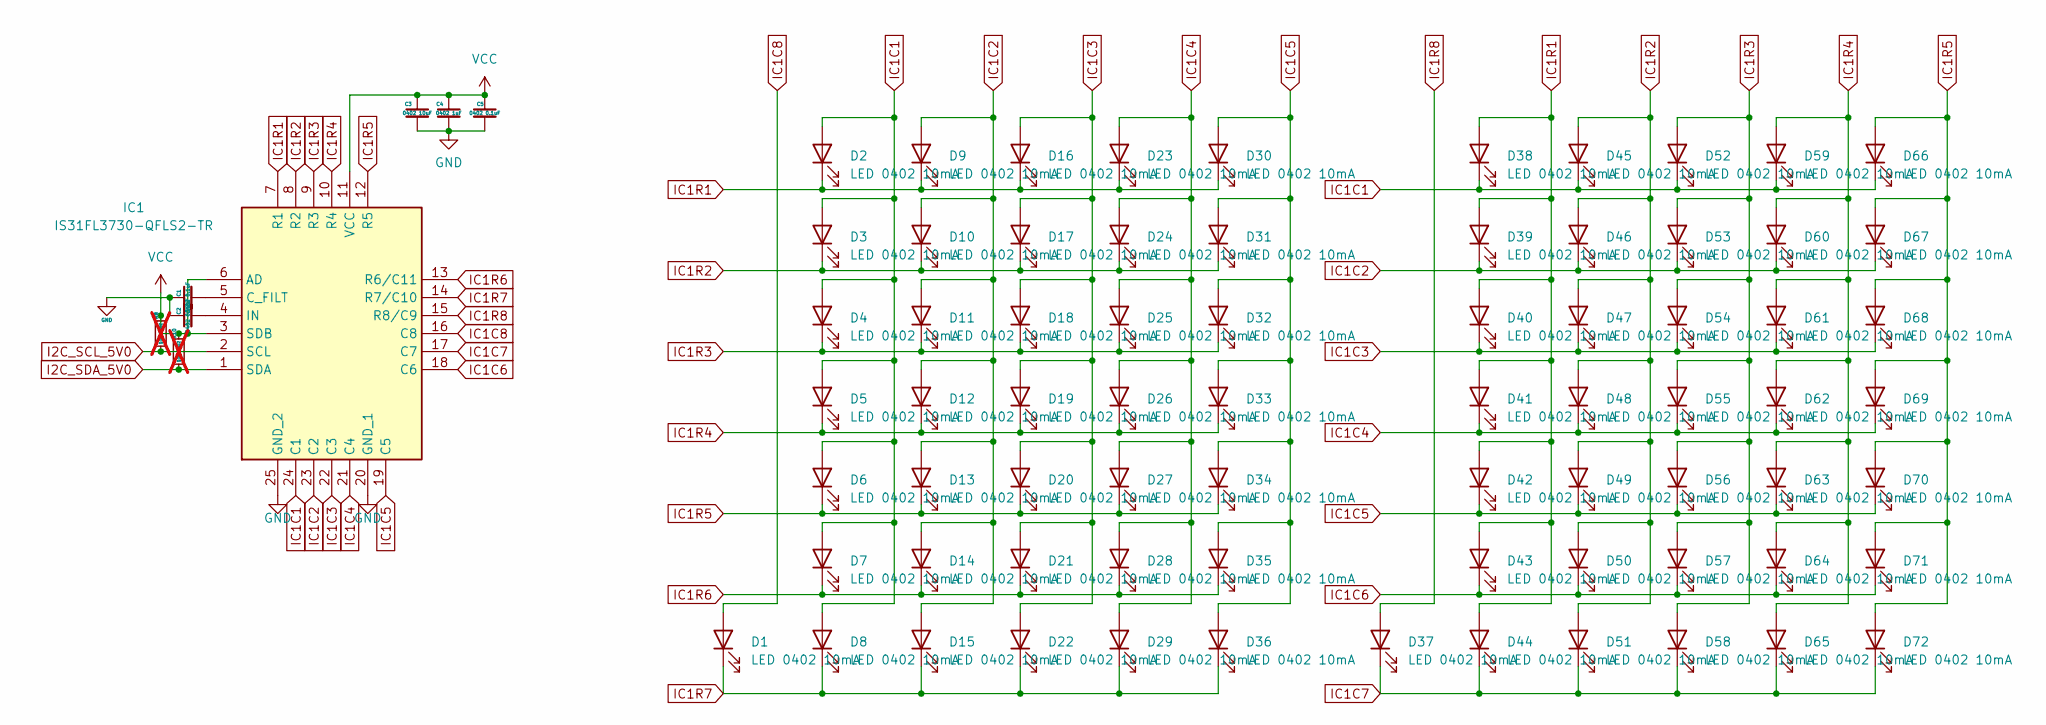
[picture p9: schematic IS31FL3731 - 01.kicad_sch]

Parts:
C1, C5: 0402 0.1uF; C_0402_1005Metric
C2: 0402 0.22uF; C_0402_1005Metric
C3: 0402 10uF; C_0402_1005Metric
C4: 0402 1uF; C_0402_1005Metric
D1, D2, D3, D4, D5, D6, D7, D8, D9, D10, D11, D12, D13, D14, D15, D16, D17, D18, D19, D20, D21, D22, D23, D24, D25, D26, D27, D28, D29, D30, D31, D32, D33, D34, D35, D36, D37, D38, D39, D40, D41, D42, D43, D44, D45, D46, D47, D48, D49, D50, D51, D52, D53, D54, D55, D56, D57, D58, D59, D60, D61, D62, D63, D64, D65, D66, D67, D68, D69, D70, D71, D72: LED 0402 10mA; LED_0402_1005Metric
IC1: IS31FL3730-QFLS2-TR; QFN-24-1EP_4x4mm_P0.5mm_EP2.6x2.6mm_ThermalVias; Mouser Part Number 870-IS31FL3730QFLS2R
R8, R10: 10K 0402; R_0402_1005Metric; not fitted

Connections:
GND: C1.1, C2.1, C3.2, C4.2, C5.2, IC1.20 (GND_1), IC1.25 (GND_2); also elsewhere on the board
I2C_SCL_5V0: IC1.2 (SCL), R8.1; also elsewhere on the board
I2C_SDA_5V0: IC1.1 (SDA), R10.1; also elsewhere on the board
IC1C1: D2.2 (A), D3.2 (A), D4.2 (A), D5.2 (A), D6.2 (A), D7.2 (A), D8.2 (A), D38.1 (K), D45.1 (K), D52.1 (K), D59.1 (K), D66.1 (K), IC1.24 (C1)
IC1C2: D9.2 (A), D10.2 (A), D11.2 (A), D12.2 (A), D13.2 (A), D14.2 (A), D15.2 (A), D39.1 (K), D46.1 (K), D53.1 (K), D60.1 (K), D67.1 (K), IC1.23 (C2)
IC1C3: D16.2 (A), D17.2 (A), D18.2 (A), D19.2 (A), D20.2 (A), D21.2 (A), D22.2 (A), D40.1 (K), D47.1 (K), D54.1 (K), D61.1 (K), D68.1 (K), IC1.22 (C3)
IC1C4: D23.2 (A), D24.2 (A), D25.2 (A), D26.2 (A), D27.2 (A), D28.2 (A), D29.2 (A), D41.1 (K), D48.1 (K), D55.1 (K), D62.1 (K), D69.1 (K), IC1.21 (C4)
IC1C5: D30.2 (A), D31.2 (A), D32.2 (A), D33.2 (A), D34.2 (A), D35.2 (A), D36.2 (A), D42.1 (K), D49.1 (K), D56.1 (K), D63.1 (K), D70.1 (K), IC1.19 (C5)
IC1C6: D43.1 (K), D50.1 (K), D57.1 (K), D64.1 (K), D71.1 (K), IC1.18 (C6)
IC1C7: D37.1 (K), D44.1 (K), D51.1 (K), D58.1 (K), D65.1 (K), D72.1 (K), IC1.17 (C7)
IC1C8: D1.2 (A), IC1.16 (C8)
IC1R1: D2.1 (K), D9.1 (K), D16.1 (K), D23.1 (K), D30.1 (K), D38.2 (A), D39.2 (A), D40.2 (A), D41.2 (A), D42.2 (A), D43.2 (A), D44.2 (A), IC1.7 (R1)
IC1R2: D3.1 (K), D10.1 (K), D17.1 (K), D24.1 (K), D31.1 (K), D45.2 (A), D46.2 (A), D47.2 (A), D48.2 (A), D49.2 (A), D50.2 (A), D51.2 (A), IC1.8 (R2)
IC1R3: D4.1 (K), D11.1 (K), D18.1 (K), D25.1 (K), D32.1 (K), D52.2 (A), D53.2 (A), D54.2 (A), D55.2 (A), D56.2 (A), D57.2 (A), D58.2 (A), IC1.9 (R3)
IC1R4: D5.1 (K), D12.1 (K), D19.1 (K), D26.1 (K), D33.1 (K), D59.2 (A), D60.2 (A), D61.2 (A), D62.2 (A), D63.2 (A), D64.2 (A), D65.2 (A), IC1.10 (R4)
IC1R5: D6.1 (K), D13.1 (K), D20.1 (K), D27.1 (K), D34.1 (K), D66.2 (A), D67.2 (A), D68.2 (A), D69.2 (A), D70.2 (A), D71.2 (A), D72.2 (A), IC1.12 (R5)
IC1R6: D7.1 (K), D14.1 (K), D21.1 (K), D28.1 (K), D35.1 (K), IC1.13 (R6/C11)
IC1R7: D1.1 (K), D8.1 (K), D15.1 (K), D22.1 (K), D29.1 (K), D36.1 (K), IC1.14 (R7/C10)
IC1R8: D37.2 (A), IC1.15 (R8/C9)
unnamed: C1.2, IC1.5 (C_FILT)
unnamed: C2.2, IC1.4 (IN)
VCC: C3.1, C4.1, C5.1, IC1.3 (SDB), IC1.6 (AD), IC1.11 (VCC), R8.2, R10.2; also elsewhere on the board

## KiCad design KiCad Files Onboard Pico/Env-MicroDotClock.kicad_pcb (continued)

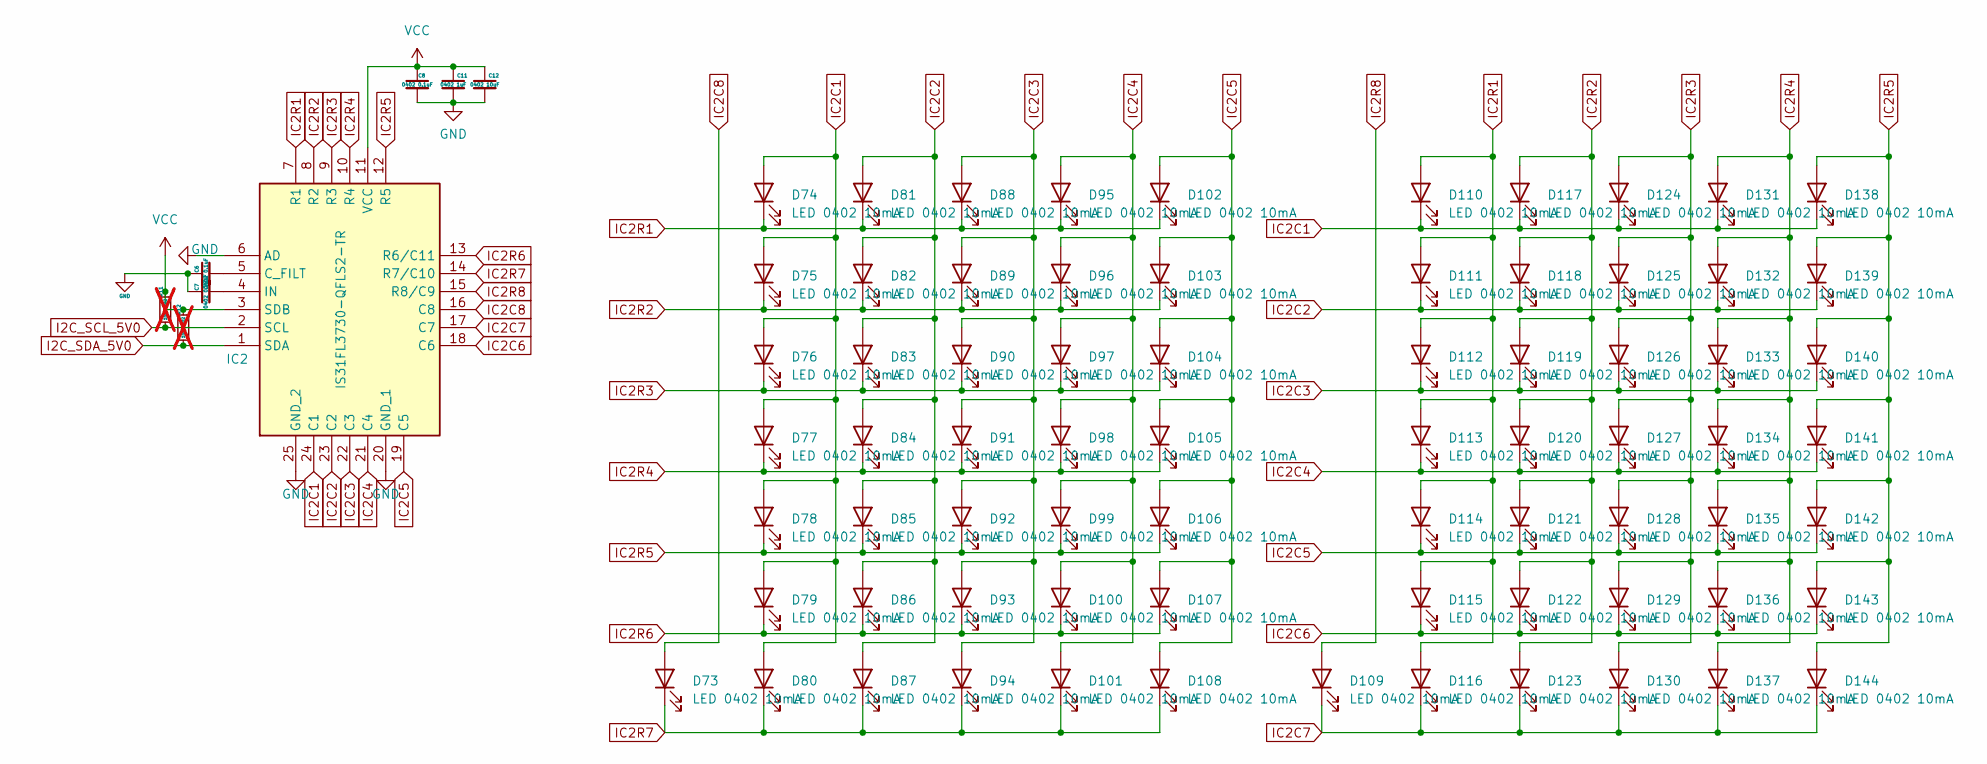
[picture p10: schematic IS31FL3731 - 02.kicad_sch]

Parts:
C6, C8: 0402 0.1uF; C_0402_1005Metric
C7: 0402 0.22uF; C_0402_1005Metric
C11: 0402 1uF; C_0402_1005Metric
C12: 0402 10uF; C_0402_1005Metric
D73, D74, D75, D76, D77, D78, D79, D80, D81, D82, D83, D84, D85, D86, D87, D88, D89, D90, D91, D92, D93, D94, D95, D96, D97, D98, D99, D100, D101, D102, D103, D104, D105, D106, D107, D108, D109, D110, D111, D112, D113, D114, D115, D116, D117, D118, D119, D120, D121, D122, D123, D124, D125, D126, D127, D128, D129, D130, D131, D132, D133, D134, D135, D136, D137, D138, D139, D140, D141, D142, D143, D144: LED 0402 10mA; LED_0402_1005Metric
IC2: IS31FL3730-QFLS2-TR; QFN-24-1EP_4x4mm_P0.5mm_EP2.6x2.6mm_ThermalVias; Mouser Part Number 870-IS31FL3730QFLS2R
R11, R12: 10K 0402; R_0402_1005Metric; not fitted

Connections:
GND: C6.1, C7.1, C8.2, C11.2, C12.2, IC2.6 (AD), IC2.20 (GND_1), IC2.25 (GND_2); also elsewhere on the board
I2C_SCL_5V0: IC2.2 (SCL), R11.1; also elsewhere on the board
I2C_SDA_5V0: IC2.1 (SDA), R12.1; also elsewhere on the board
IC2C1: D74.2 (A), D75.2 (A), D76.2 (A), D77.2 (A), D78.2 (A), D79.2 (A), D80.2 (A), D110.1 (K), D117.1 (K), D124.1 (K), D131.1 (K), D138.1 (K), IC2.24 (C1)
IC2C2: D81.2 (A), D82.2 (A), D83.2 (A), D84.2 (A), D85.2 (A), D86.2 (A), D87.2 (A), D111.1 (K), D118.1 (K), D125.1 (K), D132.1 (K), D139.1 (K), IC2.23 (C2)
IC2C3: D88.2 (A), D89.2 (A), D90.2 (A), D91.2 (A), D92.2 (A), D93.2 (A), D94.2 (A), D112.1 (K), D119.1 (K), D126.1 (K), D133.1 (K), D140.1 (K), IC2.22 (C3)
IC2C4: D95.2 (A), D96.2 (A), D97.2 (A), D98.2 (A), D99.2 (A), D100.2 (A), D101.2 (A), D113.1 (K), D120.1 (K), D127.1 (K), D134.1 (K), D141.1 (K), IC2.21 (C4)
IC2C5: D102.2 (A), D103.2 (A), D104.2 (A), D105.2 (A), D106.2 (A), D107.2 (A), D108.2 (A), D114.1 (K), D121.1 (K), D128.1 (K), D135.1 (K), D142.1 (K), IC2.19 (C5)
IC2C6: D115.1 (K), D122.1 (K), D129.1 (K), D136.1 (K), D143.1 (K), IC2.18 (C6)
IC2C7: D109.1 (K), D116.1 (K), D123.1 (K), D130.1 (K), D137.1 (K), D144.1 (K), IC2.17 (C7)
IC2C8: D73.2 (A), IC2.16 (C8)
IC2R1: D74.1 (K), D81.1 (K), D88.1 (K), D95.1 (K), D102.1 (K), D110.2 (A), D111.2 (A), D112.2 (A), D113.2 (A), D114.2 (A), D115.2 (A), D116.2 (A), IC2.7 (R1)
IC2R2: D75.1 (K), D82.1 (K), D89.1 (K), D96.1 (K), D103.1 (K), D117.2 (A), D118.2 (A), D119.2 (A), D120.2 (A), D121.2 (A), D122.2 (A), D123.2 (A), IC2.8 (R2)
IC2R3: D76.1 (K), D83.1 (K), D90.1 (K), D97.1 (K), D104.1 (K), D124.2 (A), D125.2 (A), D126.2 (A), D127.2 (A), D128.2 (A), D129.2 (A), D130.2 (A), IC2.9 (R3)
IC2R4: D77.1 (K), D84.1 (K), D91.1 (K), D98.1 (K), D105.1 (K), D131.2 (A), D132.2 (A), D133.2 (A), D134.2 (A), D135.2 (A), D136.2 (A), D137.2 (A), IC2.10 (R4)
IC2R5: D78.1 (K), D85.1 (K), D92.1 (K), D99.1 (K), D106.1 (K), D138.2 (A), D139.2 (A), D140.2 (A), D141.2 (A), D142.2 (A), D143.2 (A), D144.2 (A), IC2.12 (R5)
IC2R6: D79.1 (K), D86.1 (K), D93.1 (K), D100.1 (K), D107.1 (K), IC2.13 (R6/C11)
IC2R7: D73.1 (K), D80.1 (K), D87.1 (K), D94.1 (K), D101.1 (K), D108.1 (K), IC2.14 (R7/C10)
IC2R8: D109.2 (A), IC2.15 (R8/C9)
unnamed: C6.2, IC2.5 (C_FILT)
unnamed: C7.2, IC2.4 (IN)
VCC: C8.1, C11.1, C12.1, IC2.3 (SDB), IC2.11 (VCC), R11.2, R12.2; also elsewhere on the board

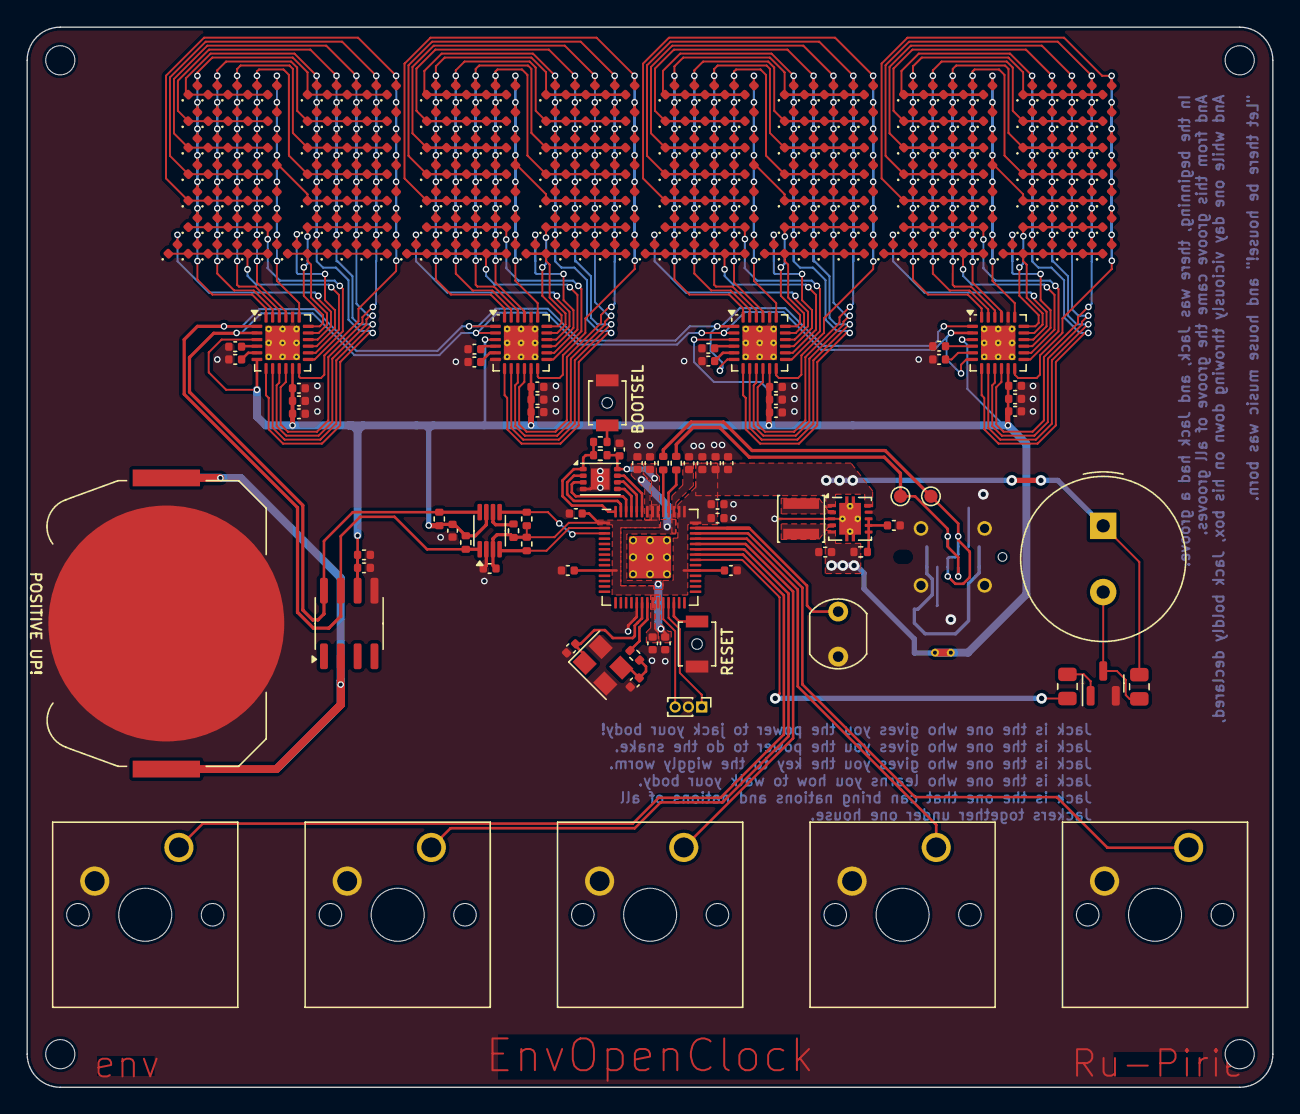
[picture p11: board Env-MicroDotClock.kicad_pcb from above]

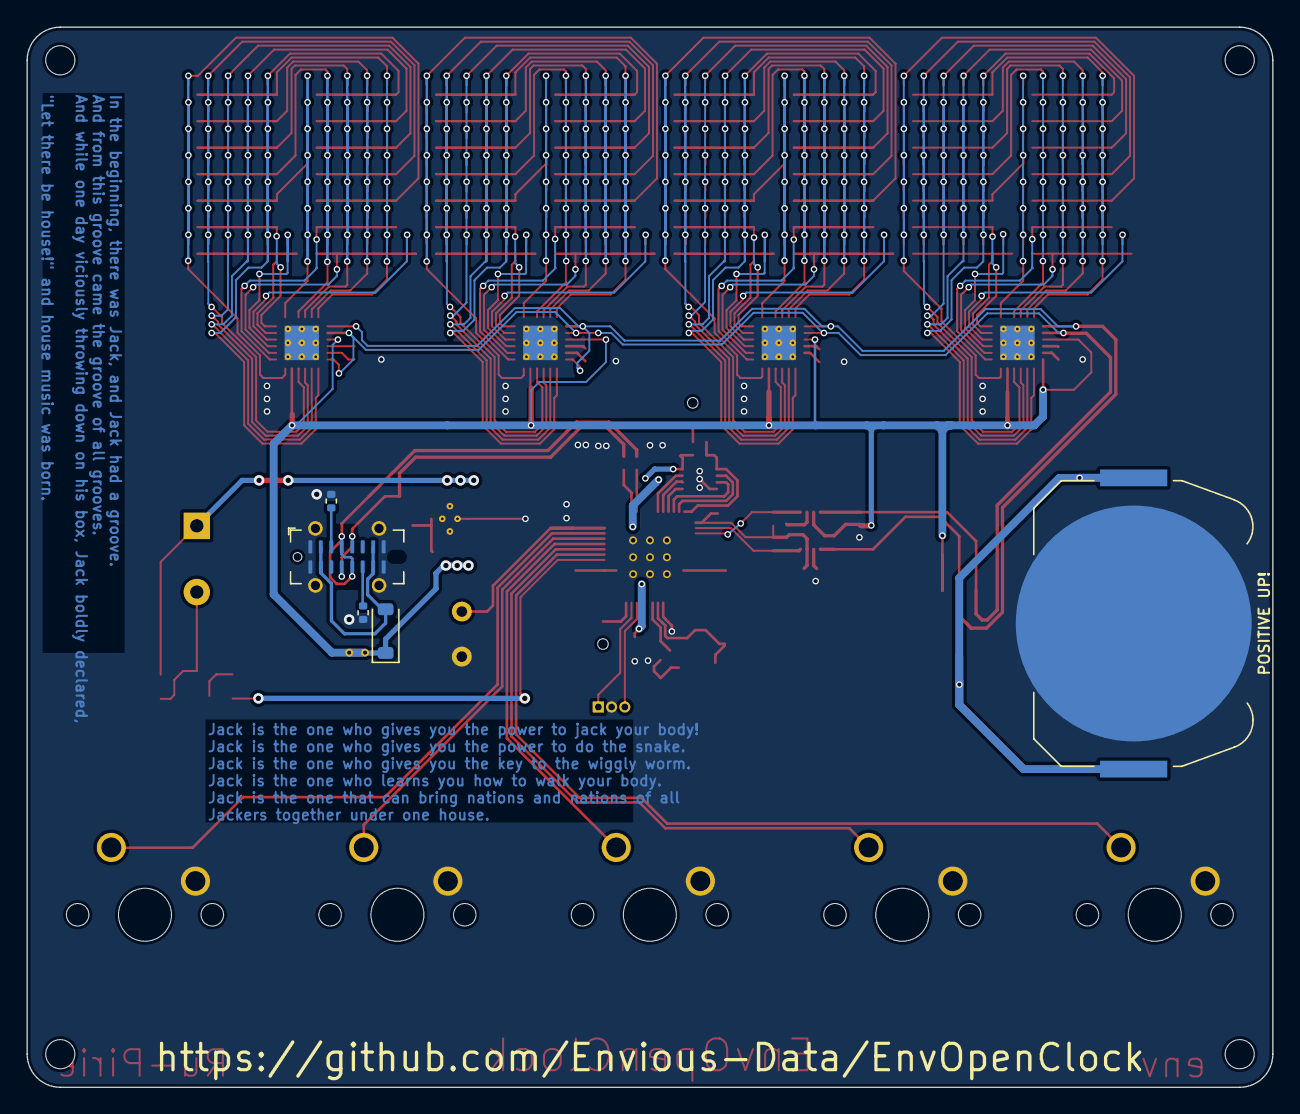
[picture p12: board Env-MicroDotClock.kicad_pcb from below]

Board: 2 copper layers, 94.0 x 80.0 mm, 378 parts (5 on the bottom side), 115 nets.

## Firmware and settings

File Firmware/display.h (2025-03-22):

#ifndef DISPLAY_H
#define DISPLAY_H

#include <stdbool.h> // Add this line
#include <stdbool.h>
#include <stdio.h>
#include <stdlib.h>
#include <time.h>

#include "hardware/i2c.h"
#include "pico/stdlib.h"

#define I2C_DISPLAY_LINE i2c1
#define I2C_DISPLAY_SDA 26
#define I2C_DISPLAY_SCL 27

#define MODE_ADDR 0b00000000
#define BRIGHTNESS_ADDR 0b00011001
#define UPDATE_ADDR 0b00001100
#define OPTION_ADDR 0b00001101
#define MATRIX_A_ADDR 0b00001110
#define MATRIX_B_ADDR 0b00000001

#define DEFAULT_MODE 0b00011000
#define DEFAULT_OPTIONS 0b00001110

#ifndef count_of
#define count_of(array) (sizeof (array) / sizeof (array[0]))
#endif

extern uint8_t brightness_level;
extern uint8_t addresses[8];
extern uint8_t displays[8][8];

void animate_slide_up (int display, char current_char, char next_char);
void animate_pixelated_transition (int display, char current_char,
                                   char next_char);
void animate_expanding_contracting (int display, char current_char,
                                    char next_char);
void animate_morph (int display, char current_char, char next_char);

// new animations
void animate_interlocking_pieces (int display, char current_char,
                                  char next_char);
void animate_glitch_effect (int display, char current_char, char next_char);
void animate_heartbeat_pulse (int display, char current_char, char next_char);
void animate_waterfall (int display, char current_char, char next_char);
void animate_clock_hand_wipe (int display, char current_char, char next_char);

// new new new animations

void convertLeftToRight (const uint8_t *left_matrix, uint8_t *right_matrix);
void pre_generate_alternate_characters ();
void set_option (int display, uint8_t address, uint8_t value);
uint8_t *prepend_address (uint8_t address, uint8_t buffer[], int buffer_size);
void update_display ();
void set_pixel (int display, uint8_t x, uint8_t y, bool status, bool update);
void set_brightness (uint8_t value); // Or int value
void clear_all (bool update);
void clear (int display, bool update);
void set_char (int display, char letter, bool update);
void get_char_data (char character, uint8_t *data);
void scroll_display_string (char *string);
void display_string (const char *string);

#endif // DISPLAY_H

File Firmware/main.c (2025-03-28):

#include <ctype.h>
#include <stdbool.h>
#include <stdio.h>
#include <stdlib.h>  // Required for rand() and srand()
#include <string.h>

#include "display.h"
#include "hardware/clocks.h"
#include "hardware/gpio.h"
#include "hardware/i2c.h"
#include "hardware/pwm.h"
#include "hardware/structs/timer.h"
#include "hardware/watchdog.h"
#include "music.h"
#include "pico/binary_info.h"
#include "pico/multicore.h"
#include "pico/stdlib.h"
#include "rtc.h"

const int song[] = {
    NOTE_E5, 4,  NOTE_B4, 8,  NOTE_C5, 8,  NOTE_D5, 4, NOTE_C5,  8,
    NOTE_B4, 8,  NOTE_A4, 4,  NOTE_A4, 8,  NOTE_C5, 8, NOTE_E5,  4,
    NOTE_D5, 8,  NOTE_C5, 8,  NOTE_B4, -4, NOTE_C5, 8, NOTE_D5,  4,
    NOTE_E5, 4,  NOTE_C5, 4,  NOTE_A4, 4,  NOTE_A4, 8, REST,     4,
    NOTE_D5, -4, NOTE_F5, 8,  NOTE_A5, 4,  NOTE_G5, 8, NOTE_F5,  8,
    NOTE_E5, -4, NOTE_C5, 8,  NOTE_E5, 4,  NOTE_D5, 8, NOTE_C5,  8,
    NOTE_B4, 4,  NOTE_B4, 8,  NOTE_C5, 8,  NOTE_D5, 4, NOTE_E5,  4,
    NOTE_C5, 4,  NOTE_A4, 4,  NOTE_A4, 4,  REST,    4, NOTE_E5,  4,
    NOTE_B4, 8,  NOTE_C5, 8,  NOTE_D5, 4,  NOTE_C5, 8, NOTE_B4,  8,
    NOTE_A4, 4,  NOTE_A4, 8,  NOTE_C5, 8,  NOTE_E5, 4, NOTE_D5,  8,
    NOTE_C5, 8,  NOTE_B4, -4, NOTE_C5, 8,  NOTE_D5, 4, NOTE_E5,  4,
    NOTE_C5, 4,  NOTE_A4, 4,  NOTE_A4, 8,  REST,    4, NOTE_D5,  -4,
    NOTE_F5, 8,  NOTE_A5, 4,  NOTE_G5, 8,  NOTE_F5, 8, NOTE_E5,  -4,
    NOTE_C5, 8,  NOTE_E5, 4,  NOTE_D5, 8,  NOTE_C5, 8, NOTE_B4,  4,
    NOTE_B4, 8,  NOTE_C5, 8,  NOTE_D5, 4,  NOTE_E5, 4, NOTE_C5,  4,
    NOTE_A4, 4,  NOTE_A4, 4,  REST,    4,  NOTE_E5, 2, NOTE_C5,  2,
    NOTE_D5, 2,  NOTE_B4, 2,  NOTE_C5, 2,  NOTE_A4, 2, NOTE_GS4, 2,
    NOTE_B4, 4,  REST,    8,  NOTE_E5, 2,  NOTE_C5, 2, NOTE_D5,  2,
    NOTE_B4, 2,  NOTE_C5, 4,  NOTE_E5, 4,  NOTE_A5, 2, NOTE_GS5, 2,
};

static char prev_hour_tens = ' ';
static char prev_hour_ones = ' ';
static char prev_minute_tens = ' ';
static char prev_minute_ones = ' ';
static char prev_second_tens = ' ';
static char prev_second_ones = ' ';

// Variables for display update timing
static uint32_t last_display_update = 0;
static const uint32_t display_update_interval_ms = 500;  // Update every 500ms

// Global flag to indicate if I2C is active
volatile bool i2c_active = false;

// Watchdog timeout in milliseconds
const uint32_t I2C_WATCHDOG_TIMEOUT_MS = 500;

// Global variable for brightness level (declared elsewhere as uint8_t brightness_level)
extern uint8_t brightness_level;

// New global flag to track if the user has manually set the brightness
volatile bool user_brightness_override = false;

// Define the brightness level for night hours
const uint8_t night_brightness_level = 0b00000001;
// Define the default day brightness level (the one set in the else condition)
const uint8_t default_day_brightness_level = 0b1101000;

// Function to set I2C active flag
void set_i2c_active(bool active) {
  i2c_active = active;
}

typedef void (*AnimationFunction)(int display_index, char previous, char current);

// Updated AnimationType enum
typedef enum {
  ANIM_SLIDE_UP,
  ANIM_PIXELATED,
  ANIM_EXPAND_CONTRACT,
  ANIM_MORPH,
  ANIM_INTERLOCKING_PIECES,
  ANIM_GLITCH_EFFECT,
  ANIM_HEARTBEAT_PULSE,
  ANIM_WATERFALL,
  ANIM_CLOCK_HAND_WIPE,
  ANIM_COUNT  // Keep this as the last element
} AnimationType;

// Updated animations array
AnimationFunction animations[] = {animate_slide_up,
                                  animate_pixelated_transition,
                                  animate_expanding_contracting,
                                  animate_morph,
                                  animate_interlocking_pieces,
                                  animate_glitch_effect,
                                  animate_heartbeat_pulse,
                                  animate_waterfall,
                                  animate_clock_hand_wipe};

// Array of animation names
const char* animation_names[] = {
    "SLIDE_UP",        "PIXELATED",           "EXPAND_CONTRACT",
    "MORPH",           "INTERLOCKING_PIECES", "GLITCH_EFFECT",
    "HEARTBEAT_PULSE", "WATERFALL",           "CLOCK_HAND_WIPE"};

AnimationType selected_animation = ANIM_SLIDE_UP;  // Default animation

void randomize_animation() {
  selected_animation = (AnimationType)(rand() % (ANIM_COUNT));
  printf("Animation set to %s.\n", animation_names[selected_animation]);
}

struct {
  uint8_t set_time : 1;
  uint8_t increment_counter : 1;
  uint8_t decrement_counter : 1;
  uint8_t set_confirm : 1;
} gpio_irq_flags;

// Debounce variables
#define DEBOUNCE_MS 50
uint32_t last_button_press[4] = {0};  // 4 buttons

extern char clock_buffer[7];
extern char* week[];

bool clock_busy = false;
bool clock_set = true;
bool show = true;                // Global variable to track the current mode
void reset_clock_static_vars();  // Function prototype

bool timer_callback(struct repeating_timer* t) {
    // Get the current hour from the clock buffer
    uint8_t current_hour = clock_buffer[2] & 0x3F;

    // Check if it's night time (after 10pm and before 6am)
    bool is_night = (current_hour >= 22 || current_hour <= 6);

    const uint8_t night_brightness_default = 0b00000001;
    const uint8_t day_brightness_default = 0b00111111; // Assuming display.c default is 63

    if (!user_brightness_override && is_night) {
        if (brightness_level > night_brightness_default) {
            // Compares against current brightness:
            // If the current brightness is greater than the night default, reduce it.
            brightness_level = night_brightness_default;
            printf("Night time: Brightness reduced to 0b%08b (%d)\n", brightness_level, brightness_level);
        }
    } else if (!user_brightness_override && !is_night) {
        // Compares against current brightness:
        // If the current brightness is equal to the night default, restore to day default.
        if (brightness_level == night_brightness_default) {
            brightness_level = day_brightness_default;
            printf("Day time: Brightness restored to default 0b%08b (%d)\n", brightness_level, brightness_level);
        }
    }
    return true; // Keep the timer repeating
}

// Function to check if it's time to update the display
bool should_update_display() {
  uint32_t current_time = to_ms_since_boot(get_absolute_time());
  if (current_time - last_display_update >= display_update_interval_ms) {
    last_display_update = current_time;
    return true;
  }
  return false;
}

bool update_date() {
  if (clock_set) {
    char* date_string_buffer = malloc(100);
    if (date_string_buffer == NULL) {
      return false;
    }

    clock_read_time();

    clock_buffer[4] &= 0x7F;  // day
    clock_buffer[5] &= 0x7F;  // month
    clock_buffer[6] &= 0x3F;  // year

    sprintf(date_string_buffer, "%02x/%02x/%02x", clock_buffer[4],
            clock_buffer[5], clock_buffer[6]);
    display_string(date_string_buffer);
    free(date_string_buffer);
    set_char(2, '/', false);
    set_char(5, '/', false);
    return false;
  }
  return false;
}

int calculate_frequency(uint frequency) {
  // 1Hz is once per second
  // Delay is the time in microseconds to sleep
  int delay = (double)100000 / frequency;
  return delay >> 1;
}

// UPDATE CLOCK BIT
bool update_clock() {
  if (!clock_set)
    return false;

  char clock_string_buffer[9];
  clock_read_time();

  uint8_t hour = clock_buffer[2] & 0x3F;
  uint8_t minute = clock_buffer[1] & 0x7F;
  uint8_t second = clock_buffer[0] & 0x7F;

  snprintf(clock_string_buffer, sizeof(clock_string_buffer), "%02x:%02x:%02x",
           hour, minute, second);

  char hour_tens = clock_string_buffer[0];
  char hour_ones = clock_string_buffer[1];
  char minute_tens = clock_string_buffer[3];
  char minute_ones = clock_string_buffer[4];
  char second_tens = clock_string_buffer[6];
  char second_ones = clock_string_buffer[7];

  struct {
    char current;
    char previous;
    int display_index;
  } digits[] = {
      {hour_tens, prev_hour_tens, 0},     {hour_ones, prev_hour_ones, 1},
      {minute_tens, prev_minute_tens, 3}, {minute_ones, prev_minute_ones, 4},
      {second_tens, prev_second_tens, 6}, {second_ones, prev_second_ones, 7}};

  for (int i = 0; i < sizeof(digits) / sizeof(digits[0]); i++) {
    if (digits[i].previous == ' ') {
      set_char(digits[i].display_index, digits[i].current, false);
    } else if (digits[i].current != digits[i].previous) {
      // Simple approach - use the animations function array
      if (selected_animation < ANIM_COUNT) {
        animations[selected_animation](digits[i].display_index,
                                       digits[i].previous, digits[i].current);
      }
    }
  }

  // Update previous values
  prev_hour_tens = hour_tens;
  prev_hour_ones = hour_ones;
  prev_minute_tens = minute_tens;
  prev_minute_ones = minute_ones;
  prev_second_tens = second_tens;
  prev_second_ones = second_ones;

  set_char(2, ':', false);
  set_char(5, ':', false);

  return true;
}

void set_date_and_time() {
  clear_all(false);
  update_display();  // Ensure full clear
  clock_set = true;

  struct {
    const char* prompt;
    int* value;
    int min;
    int max;
  } settings[] = {{"Year:", &(int){23}, 0, 99},  {"Month:", &(int){1}, 1, 12},
                  {"Day:", &(int){1}, 1, 31},    {"Hour:", &(int){0}, 0, 23},
                  {"Minute:", &(int){0}, 0, 59}, {"Second:", &(int){0}, 0, 59}};

  for (int i = 0; i < sizeof(settings) / sizeof(settings[0]); i++) {
    clear_all(false);
    update_display();  // Ensure full clear
    int* value = settings[i].value;

    if (strcmp(settings[i].prompt, "Day:") == 0) {
      int month = *(settings[1].value);
      int year = *(settings[0].value) + 2000;
      int max_days[] = {
          31, (year % 4 == 0 && (year % 100 != 0 || year % 400 == 0)) ? 29 : 28,
          31, 30,
          31, 30,
          31, 31,
          30, 31,
          30, 31};
      settings[i].max = max_days[month - 1];
    }

    while (!gpio_irq_flags.set_confirm) {
      if (!gpio_irq_flags.decrement_counter ||
          !gpio_irq_flags.increment_counter) {
        if (gpio_irq_flags.decrement_counter) {
          *value = (*value > settings[i].min) ? *value - 1 : settings[i].max;
          gpio_irq_flags.decrement_counter = 0;
        }
        if (gpio_irq_flags.increment_counter) {
          *value = (*value < settings[i].max) ? *value + 1 : settings[i].min;
          gpio_irq_flags.increment_counter = 0;
        }

        display_string(settings[i].prompt);
        set_char(6, '0' + (*value / 10), false);
        set_char(7, '0' + (*value % 10), true);
      }
    }
    gpio_irq_flags.set_confirm = 0;
    if (i == 4) {  // if minutes were just set.
      clear(3, false);
      clear(4, false);
      update_display();
    }
  }

  clock_set_time(
      int_to_bcd(*(settings[5].value)), int_to_bcd(*(settings[4].value)),
      int_to_bcd(*(settings[3].value)), int_to_bcd(*(settings[2].value)),
      int_to_bcd(*(settings[1].value)), int_to_bcd(*(settings[0].value)));

  clock_read_time();

  // Display full time with separators
  char time_string[9];
  snprintf(time_string, sizeof(time_string), "%02x:%02x:%02x",
           clock_buffer[2] & 0x3F, clock_buffer[1] & 0x7F,
           clock_buffer[0] & 0x7F);
  display_string(time_string);
  set_char(2, ':', false);
  set_char(5, ':', false);
  update_display();
}

void cycle_brightness() {
    user_brightness_override = true; // Set the flag when user changes brightness
    if (brightness_level == 0b00111111) { // Currently at max (63)
        brightness_level = 0b00110000;     // Go to 48
    } else if (brightness_level == 0b00110000) { // Currently at 48
        brightness_level = 0b00011111;     // Go to 31
    } else if (brightness_level == 0b00011111) { // Currently at 31
        brightness_level = 0b00001111;     // Go to 15
    } else if (brightness_level == 0b00001111) { // Currently at 15
        brightness_level = 0b00000001;     // Go to 1
    } else {                                  // Catch-all: If at 1 or something else
        brightness_level = 0b00111111;     // Cycle back to max (63)
    }
    printf("Brightness level set to: 0b%08b (%d)\n", brightness_level, brightness_level);
    // The brightness will be updated in the main loop implicitly
}

void gpio_iqr_handler(uint gpio, uint32_t event) {
    uint32_t current_time = to_ms_since_boot(get_absolute_time());
    int button_index = -1;

    switch (gpio) {
        case 2:
            button_index = 0;
            break;
        case 3:
            button_index = 1;
            break;
        case 4:
            button_index = 2;
            break;
        case 5:
            button_index = 3;
            break;
    }

    if (button_index != -1 &&
        (current_time - last_button_press[button_index]) > DEBOUNCE_MS) {
        last_button_press[button_index] = current_time;

        switch (gpio) {
            case 2:
                gpio_irq_flags.set_time = 1;
                break;
            case 3: // Increment button (now switches animations)
                gpio_irq_flags.increment_counter = 1;
                break;
            case 4: // Third button now cycles brightness
                cycle_brightness();
                break;
            case 5:
                gpio_irq_flags.set_confirm = 1;
                break;
        }
    }
    return;
}

void core1_entry() {
  char serial_buffer[100];
  while (true) {
    if (fgets(serial_buffer, sizeof(serial_buffer), stdin) != NULL) {
      if (strncmp(serial_buffer, "settime", 7) == 0) {
        int year, month, day, hour, minute, second;
        if (sscanf(serial_buffer, "settime %d-%d-%d %d:%d:%d", &year, &month,
                   &day, &hour, &minute, &second) == 6) {
          clock_set_time(int_to_bcd(second), int_to_bcd(minute),
                         int_to_bcd(hour), int_to_bcd(day), int_to_bcd(month),
                         int_to_bcd(year % 100));
          clock_read_time();
          printf("Time set from serial input.\n");
        } else {
          printf("Invalid time format.\n");
        }
      } else if (strncmp(serial_buffer, "reset", 5) == 0) {
        clear_all(true);
        printf("Resetting Pico...\n");
        sleep_ms(100);
        watchdog_enable(1, 1);
        while (1)
          ;
      } else if (strncmp(serial_buffer, "anim ", 5) == 0) {
        int anim_num;
        if (sscanf(serial_buffer, "anim %d", &anim_num) == 1) {
          if (anim_num >= 0 && anim_num < ANIM_COUNT) {
            selected_animation = (AnimationType)anim_num;
            printf("Animation set to %d.\n", anim_num);
          } else {
            printf("Invalid animation number. Must be between 0 and %d.\n",
                   ANIM_COUNT - 1);
          }
        } else {
          printf("Invalid animation command format. Use 'anim <number>'.\n");
        }
      } else {
        printf("Unknown command: %s", serial_buffer);
      }
    }

    if (i2c_active) {
      watchdog_enable(I2C_WATCHDOG_TIMEOUT_MS, 1);
      watchdog_update();
    } else {
      watchdog_enable(1, 0);
    }
  }
}
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

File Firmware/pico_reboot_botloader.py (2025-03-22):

import serial
import serial.tools.list_ports
import time
import shutil
import os
import logging

def reset_pico_to_bootloader(baud_rate=1200, retries=1, retry_delay=1):
    """Resets Pico to bootloader with improved error handling."""
    ports = list(serial.tools.list_ports.comports())
    if not ports:
        return False
    selected_port = ports[0].device
    logging.info(f"Resetting Pico via serial port {selected_port} at 1200 baud.")
    try:
        ser = serial.Serial(selected_port, baud_rate, timeout=1)
        ser.setDTR(False)
        ser.setRTS(True)
        time.sleep(0.1)
        ser.setRTS(False)
        time.sleep(0.1)
        ser.close()
        logging.info(f"Pico reset attempt on {selected_port}.")
        return True
    except Exception as e:
        return False #suppress serial port error

def find_pico_drive(drive_name="RPI-RP2"):
    """Simplified drive check."""
    for drive in "ABCDEFGHIJKLMNOPQRSTUVWXYZ":
        drive_path = os.path.normpath(f"{drive}:\\")
        if os.path.exists(os.path.join(drive_path, "INFO_UF2.TXT")):
            try:
                with open(os.path.join(drive_path, "INFO_UF2.TXT"), "r") as f:
                    if drive_name in f.read():
                        return drive_path
            except:
                pass
    return None

def copy_uf2_to_pico(uf2_path, pico_drive):
    """Copies .uf2 to the Pico."""
    try:
        shutil.copy2(uf2_path, pico_drive)
        logging.info(f"Copied {uf2_path} to {pico_drive}.")
        return True
    except FileNotFoundError:
        logging.error(f"Error: {uf2_path} not found.")
        return False
    except PermissionError:
        logging.error(f"Error: Permission denied to {pico_drive}.")
        return False
    except Exception as e:
        logging.error(f"Error: {e}")
        return False

if __name__ == "__main__":
    logging.basicConfig(level=logging.INFO, format='%(asctime)s - %(levelname)s - %(message)s')
    ports = list(serial.tools.list_ports.comports())
    if not ports:
        logging.info("No serial ports found. Checking for bootloader mode...")
        time.sleep(1)  # Initial delay
        for i in range(5):  # Try 5 times
            logging.info(f"Checking for Pico drive, attempt {i+1}")
            pico_drive = find_pico_drive()
            if pico_drive:
                logging.info(f"Pico drive found: {pico_drive}")
                logging.info(f"Found Pico in bootloader, copying file now.")
                uf2_file = r"C:\\Users\\Envy\\Documents\\GitHub\\EnvOpenClock\\Firmware\\clock.uf2"
                copy_uf2_to_pico(uf2_file, pico_drive)
                break
            else:
                logging.info(f"Attempt {i + 1}: Pico drive not found. Waiting...")
                time.sleep(1)  # Increase delay each time
        else:
            logging.error("Pico drive not found after multiple attempts.")
    else:
        logging.info("Serial port detected, attempting to reset Pico to bootloader.")
        reset_pico_to_bootloader() #attempt reset
        logging.info("Waiting for Pico to enter bootloader mode.")
        time.sleep(1) #wait for drive to appear
        pico_drive = None
        for i in range(5):
            logging.info(f"Checking for Pico drive, attempt {i+1}")
            pico_drive = find_pico_drive()
            if pico_drive:
                break;
            else:
                time.sleep(1)
        if pico_drive:
            logging.info(f"Pico drive found: {pico_drive}")
            logging.info(f"Pico found after reset, copying file now.")
            uf2_file = r"C:\\Users\\Envy\\Documents\\GitHub\\EnvOpenClock\\Firmware\\clock.uf2"
            copy_uf2_to_pico(uf2_file, pico_drive)
        else:
            logging.error("Pico drive not found after reset attempt.")

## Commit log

2023-06-05 First commit.
    [Env-MicroDotClock.kicad_pcb, Env-MicroDotClock.kicad_sch, LTP-305G.stp]
2023-06-05 generated production files for JLCPCB.
    [bom.csv, designators.csv, positions.csv]
2023-06-05 small changes and fixes, among other adjustments.
    [Env-MicroDotClock.kicad_pcb, Env-MicroDotClock.kicad_sch, bom.csv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]
2023-06-06 some fixes and adjustments.
    [Env-MicroDotClock.kicad_pcb]
2023-06-07 Moved LTP305s up and the matrix ICs below the LTP305s
    [Env-MicroDotClock.kicad_pcb, Env-MicroDotClock.kicad_sch]
2023-06-07 updated production files
    [Env-MicroDotClock.kicad_pcb, bom.csv, positions.csv]
2023-06-10 added dip switch for summer time adjustment
    [Env-MicroDotClock.kicad_pcb, Env-MicroDotClock.kicad_sch]
2023-06-10 swapped dipswitch for smaller
    [Env-MicroDotClock.kicad_pcb, Env-MicroDotClock.kicad_sch]
2023-07-05 dont recall what I changed, probably cleaned some bits up before generating gerber
    [Env-MicroDotClock.kicad_pcb, Env-MicroDotClock.kicad_sch, bom.csv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]
2023-07-11 updated to reflect current vision.
    [Env-MicroDotClock.kicad_pcb, Env-MicroDotClock.kicad_sch]
2023-07-20 made values more descriptive for SMTA
    [Env-MicroDotClock.kicad_sch]
2023-08-19 Fixed pullups, they ran to 5V instead of 3.3V meaning they would fry the MCU pins eventually
    [Env-MicroDotClock.kicad_pcb, Env-MicroDotClock.kicad_sch]
2023-08-21 rotated the battery holder so the battery inserts from the side.
    [Env-MicroDotClock.kicad_pcb, Env-MicroDotClock.kicad_sch]
2023-08-21 updated battery Silkscreen
    [Env-MicroDotClock.kicad_pcb]
2023-08-21 Revert "added timouts"
    This reverts commit 298f98d779afaf4c9fa04b243778e5b8981776b4.
    [display.c, main.c, rtc.c]
2023-08-23 adjusted silkscreen again
    [Env-MicroDotClock.kicad_pcb]
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2023-08-23 testing chip 3 - failed
    [main.c]
2023-08-24 Added comments to display driver
    [Env-MicroDotClock.kicad_pcb]
2023-08-26 swapped 5V for 3V3 as per information on the datasheet
    [Env-MicroDotClock.kicad_pcb, Env-MicroDotClock.kicad_sch]
2023-08-26 moved all i2c devices to dedicated gpio pairs, added individual pullups, ensured everything is 3.3V VCC or logic level 3V3 tied
    [Env-MicroDotClock.kicad_pcb, Env-MicroDotClock.kicad_sch, Pico-R3.step]
2023-08-26 changes toward a V2, replaced battery holder with larger one, moved rtc leftward to make space for larger battery.
    [Env-MicroDotClock.kicad_pcb, Env-MicroDotClock.kicad_sch]
2023-08-26 small tweaks + generated production files
    [Env-MicroDotClock.kicad_pcb, bom.csv, designators.csv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]
2023-08-28 removed all traces for work on future version
    [Env-MicroDotClock.kicad_pcb, Env-MicroDotClock.kicad_sch]
2023-08-28 added a simple stand for the clock
    [Simple Stand.stl]
2023-08-29 Kicad Verion
    [Env-MicroDotClock.kicad_pcb]
2023-08-29 Kicad Verion - Power Traces Alone
    [Env-MicroDotClock.kicad_pcb]
2023-08-29 Revert "Kicad Verion - Power Traces Alone"
    This reverts commit 158b1d36a461ef127bb1067e7f7cef4c0585e52c.
    [Env-MicroDotClock.kicad_pcb]
2023-08-30 ru version
    [Env-MicroDotClock-rounded.kicad_pcb]
2023-08-30 aligned and organized components on main variant
    [Env-MicroDotClock.kicad_pcb]
2023-08-30 overhauled PCB traces and deleted old production files
    [Env-MicroDotClock.kicad_pcb, bom.csv, designators.csv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]
2023-09-09 fixed up some issues I saw, general improvements and adjustments to PCB
    [Env-MicroDotClock-rounded.kicad_pcb, Env-MicroDotClock.kicad_pcb]
2023-09-09 made a roundfied version
    [Env-MicroDotClock-rounded.kicad_pcb]
2023-09-09 rename 1 file
    [Env-MicroDotClock.kicad_pcb]
2023-09-09 Added Signatures
    [Env-MicroDotClock.kicad_pcb, bom.csv, designators.csv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]
2023-09-09 Added debugging headder and sig
    [Env-MicroDotClock.kicad_pcb]
2023-09-10 schema push
    [Env-MicroDotClock.kicad_sch]
2023-09-10 prettied up pcb some more and organised schematic
    [Env-MicroDotClock.kicad_pcb, Env-MicroDotClock.kicad_sch]
2023-09-10 added more buttons, re-worked some bits and pieces here and there.
    [Env-MicroDotClock.kicad_pcb, Env-MicroDotClock.kicad_sch]
2023-09-10 added missing teardrops and fixed a couple overlapped traces
    [Env-MicroDotClock.kicad_pcb]
2023-09-11 added leds on board (LOB)
    [Env-MicroDotClock.kicad_pcb, Env-MicroDotClock.kicad_sch, LTP-305G.stp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]
2023-09-11 begin autorouter
    [Env-MicroDotClock.kicad_pcb]
2023-09-11 Fully wired V1 LOB
    [Env-MicroDotClock.kicad_pcb]
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2023-09-15 Re-worked board to have optional VCC source, rear usb and a few other adjustments
    [Env-MicroDotClock.kicad_pcb, Env-MicroDotClock.kicad_sch]
2023-09-18 adjusted a couple traces I Didnt like
    [Env-MicroDotClock.kicad_pcb]
2023-09-20 Added ability to set time and show date!
    [Env-MicroDotClock-rounded.kicad_pcb]
2023-09-21 removed buzzer so I could fit USB port in a better place, allowing for a pimoroni lipo shim to be installed
    [Env-MicroDotClock.kicad_pcb, Env-MicroDotClock.kicad_sch]
2023-09-21 cleaned up production files..
    [bom.csv, designators.csv, positions.csv]
2023-10-07 Added Pico On Board
    [Env-MicroDotClock.kicad_pcb, Env-MicroDotClock.kicad_sch, LTP-305G.stp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]
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2023-10-08 for cat with onboard pico
    [untitled.kicad_sch]
2023-10-08 Commit for night, progess on onboard RP2040
    [Env-MicroDotClock.kicad_pcb]
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2023-10-10 Finished V1 Placement of onboard pico
    [Env-MicroDotClock.kicad_pcb, Env-MicroDotClock.kicad_sch, untitled.kicad_sch]
2023-10-10 Finished V2 placement and base wireing of RP2040
    [Env-MicroDotClock.kicad_pcb, Env-MicroDotClock.kicad_sch]
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2024-04-01 began rework of onboard 2040 pcb
    [Env-MicroDotClock.kicad_pcb, Env-MicroDotClock.kicad_sch, untitled.kicad_sch]
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2024-04-01 finished up and cleaned up PCB, added logos
    [Env-MicroDotClock.kicad_pcb, Env-MicroDotClock.kicad_sch, untitled.kicad_sch]
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2024-04-20 added thermal vias, improved gnd connections from IS31FL37s, added thermal vias, added power only usb port on the back.
    [Env-MicroDotClock.kicad_pcb, untitled.kicad_sch]
2024-06-05 swapped LDO for more capable switching regulator.
    [Env-MicroDotClock.kicad_pcb, untitled.kicad_sch]
2024-08-23 added a text note
    [Env-MicroDotClock.kicad_sch, untitled.kicad_sch]
2024-08-28 Moved all ICs to one i2c bus, removed SI7021, added i2c level shifters.
    [Env-MicroDotClock.kicad_pcb, Env-MicroDotClock.kicad_sch, untitled.kicad_sch]
2024-09-12 Fixed issues with I2C, added I2C shifter
    [Env-MicroDotClock.kicad_pcb, Env-MicroDotClock.kicad_sch]
2024-09-12 corrected couple missing connections
    [Env-MicroDotClock.kicad_pcb, Env-MicroDotClock.kicad_sch]
2024-09-12 forgot to fill zone
    [Env-MicroDotClock.kicad_sch]
2024-09-12 removed sockets, added level shifter IC, changed RTC to smaller package, re-did entire board to be more tidy.
    [Env-MicroDotClock.kicad_pcb, Env-MicroDotClock.kicad_sch, IS31FL3731 - 01.kicad_sch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]
2024-09-12 added some silkscreen labels
    [Env-MicroDotClock.kicad_pcb]
2024-10-15 corrected schematic file name
    [Env-MicroDotClock.kicad_sch, MCU.kicad_sch]
2024-11-21 small corrections
    [Env-MicroDotClock.kicad_pcb, MCU.kicad_sch]
2025-03-18 added a sliding animation, still some issues to work out like seperators not showing on startup.
    [display.c, display.h, main.c]
2025-03-18 one very silly fix for missing separators on start-up.
    [main.c]
2025-03-18 fixed the semicolon issue, added startup message, added python script to sync time to the clock from your pc.
    [main.c]
2025-03-18 sped up animation speed, added reset via serial and attempted to add a watchdog for i2c hang.
    [display.c, main.c]
2025-03-19 supressed errors, added various prints to whats going on.
    [pico_reboot_botloader.py]
2025-03-19 added a basic debounce as it was easy to skip over animations when pressing the button to cycle them.
    [main.c]
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2025-03-28 corrected orientation of various animations, made the date and time mode use the current animation instead of slide up.
    [display.c, main.c]
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
